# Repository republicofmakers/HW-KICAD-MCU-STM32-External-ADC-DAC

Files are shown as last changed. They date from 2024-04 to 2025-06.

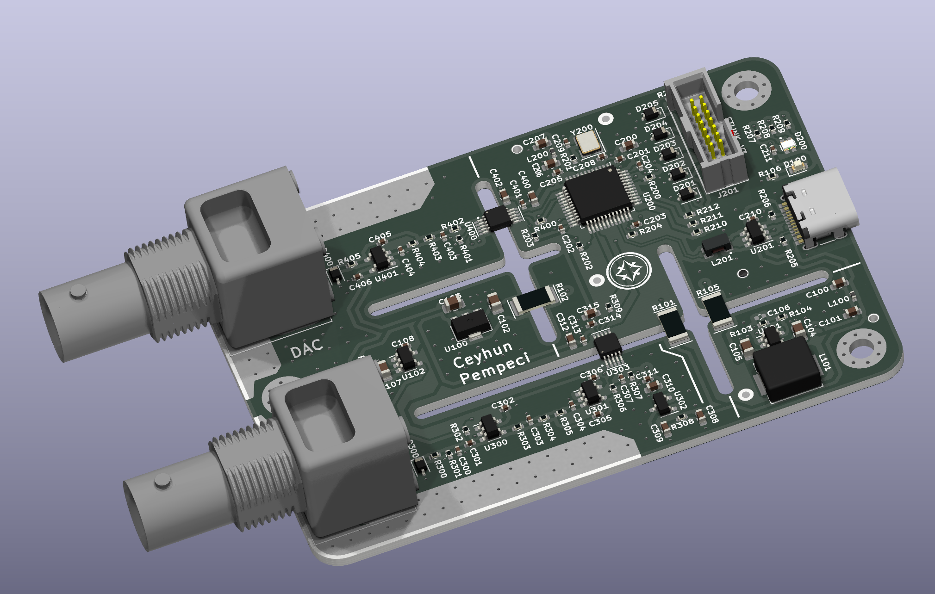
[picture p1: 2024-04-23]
Documents/Pictures/Picture-Front1.png

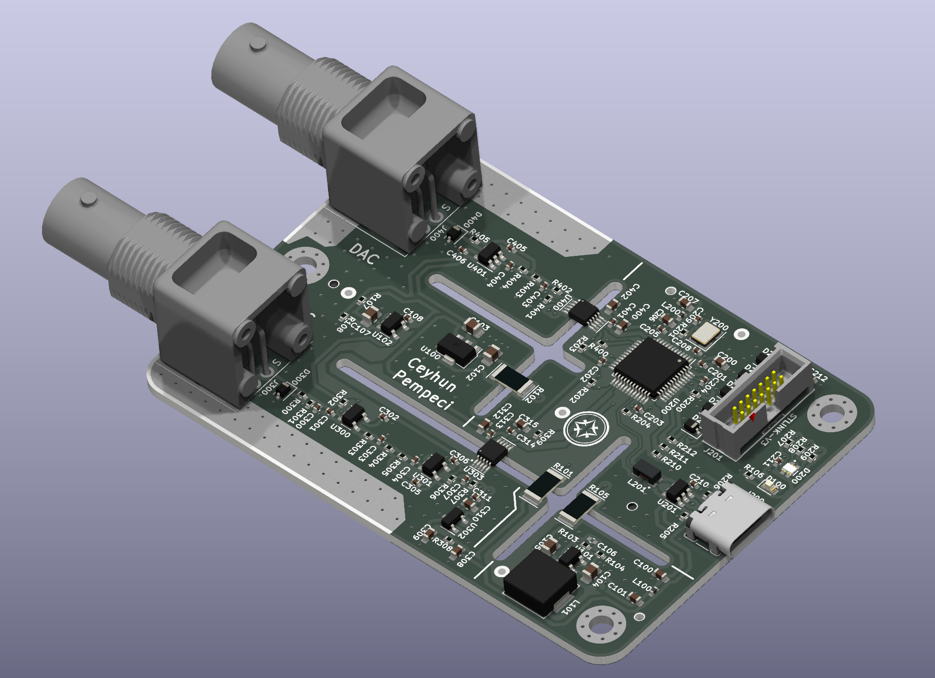
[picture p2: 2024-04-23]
Documents/Pictures/Picture-Front2.png

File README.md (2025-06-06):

# Mixed Signal Hardware Design

Picture-Front1
Image generated with Kicad 3D viewer.
  <br />
  
* You can download and check the project in Kicad.
* You can order this board (incl. SMT assembly) at https://www.jlcpcb.com. 
* Gerber and assembly files are in the relevant repo folders.

# With this project you can learn how to design:
* Switching voltage regulator and Low-dropout regulator
* STM32 MCU that using USB & SPI interface
* ADC / DAC integration
* Creating kalman filter for noise
* Also how to isolate the part with PCB cutouts for noise

NOTE:If you are an employer , you can check out my skills...

# Where can you use it?
* If you need many ADC or DAC readings, STM32 have limited number of ADC/DAC , such as if you design an SDD tester etc. 
* If you need more accurate readings, I used 14-Bit for ADC and 12-Bit for DAC but you can go 16-BIT or more...
* ADC => (ADC141S626 14-Bit, 50 kSPS to 250 kSPS)
* DAC => (DAC7563SDGSR 12-Bit, 0 to 3.3V)
* I used these parts because I had at my invertory, but I think you get the idea.
* If you need filtering for noise, kalman filters are so common in industry. Drones etc.<br />
Don't forget the test with LTSPICE.
<br />
<br />
* Take the project, adapt it , use it. I hope it helps you...

<br />
<br />

 **STM32F1 based ADC / DAC signal analyzer** 

 **Mixed Signal Hardware Design with Kicad** 

 **Created By Ceyhun Pempeci**

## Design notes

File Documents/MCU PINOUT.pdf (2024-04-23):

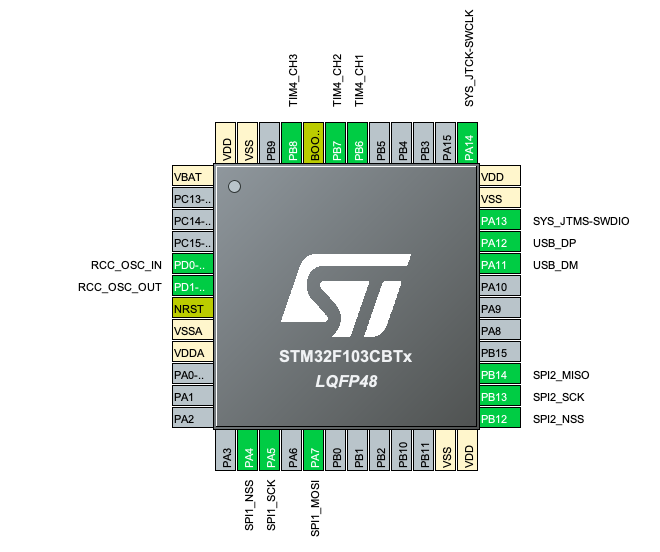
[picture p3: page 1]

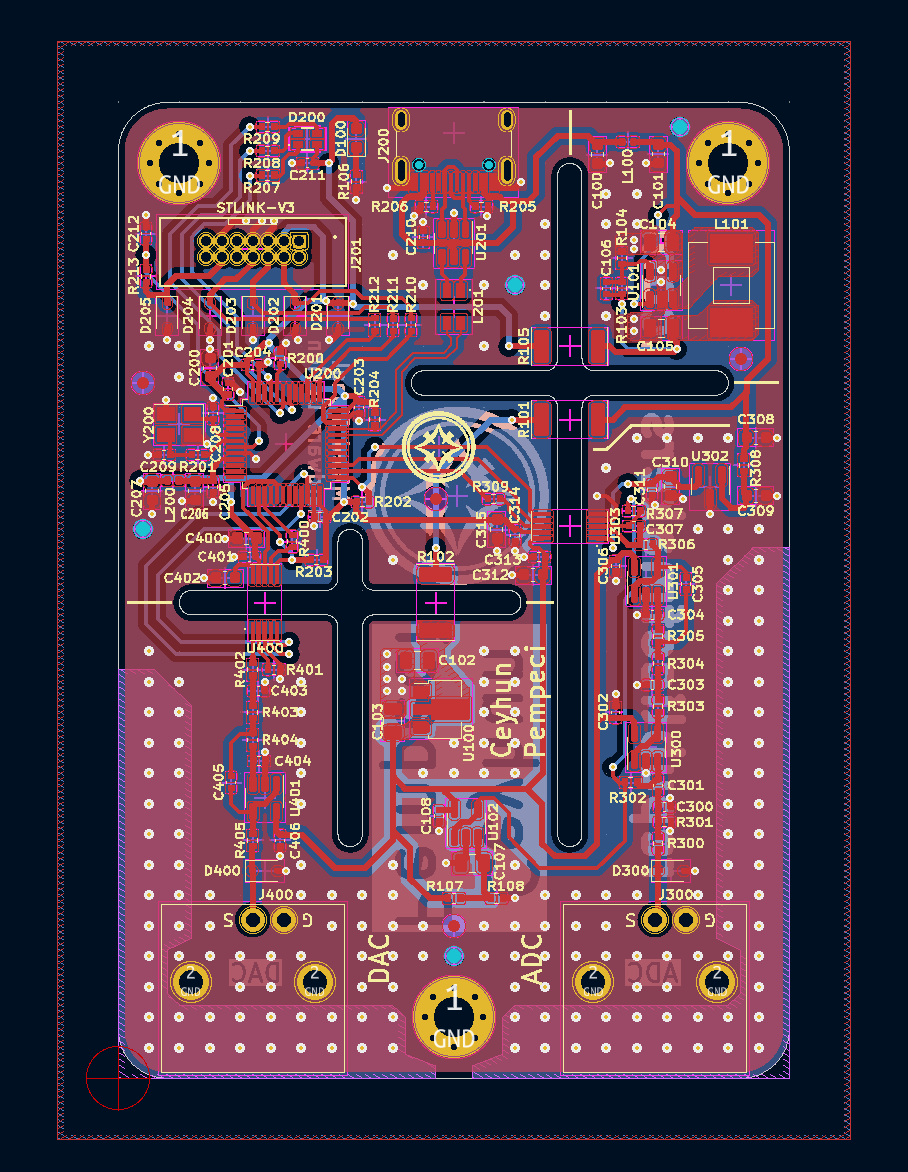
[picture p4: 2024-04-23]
Documents/Pictures/PCB-Final2.png

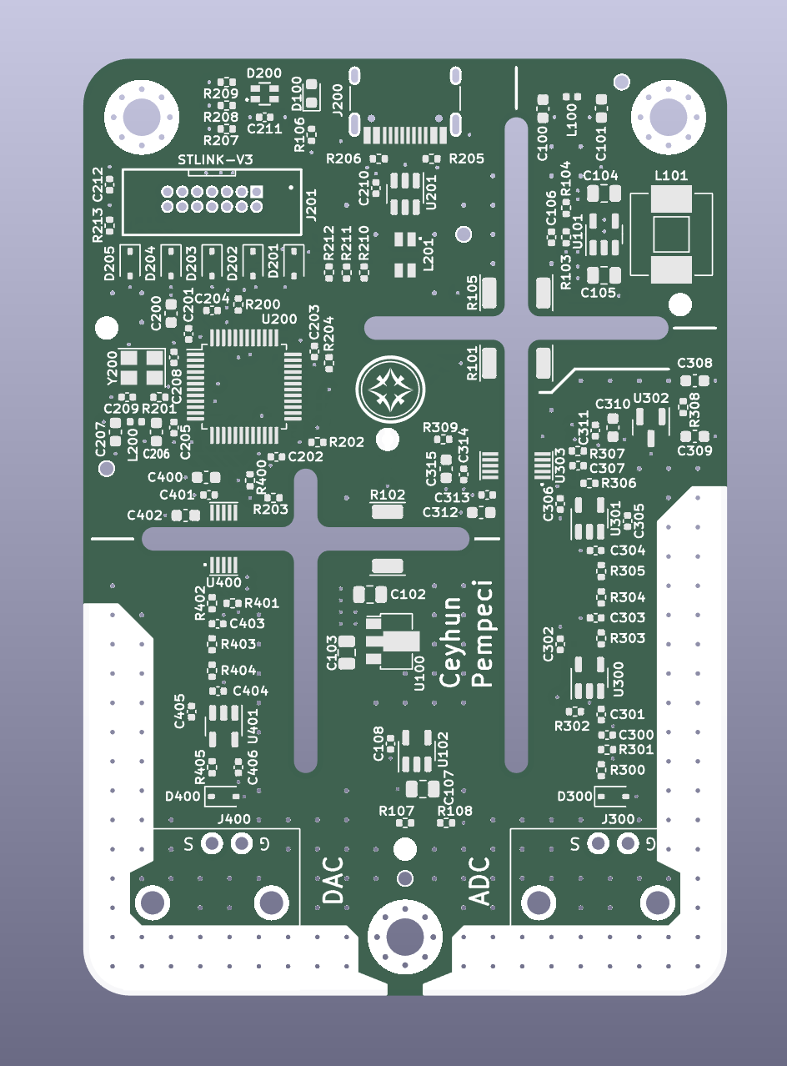
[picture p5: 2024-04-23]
Documents/Pictures/Picture-PCB-Raw.png

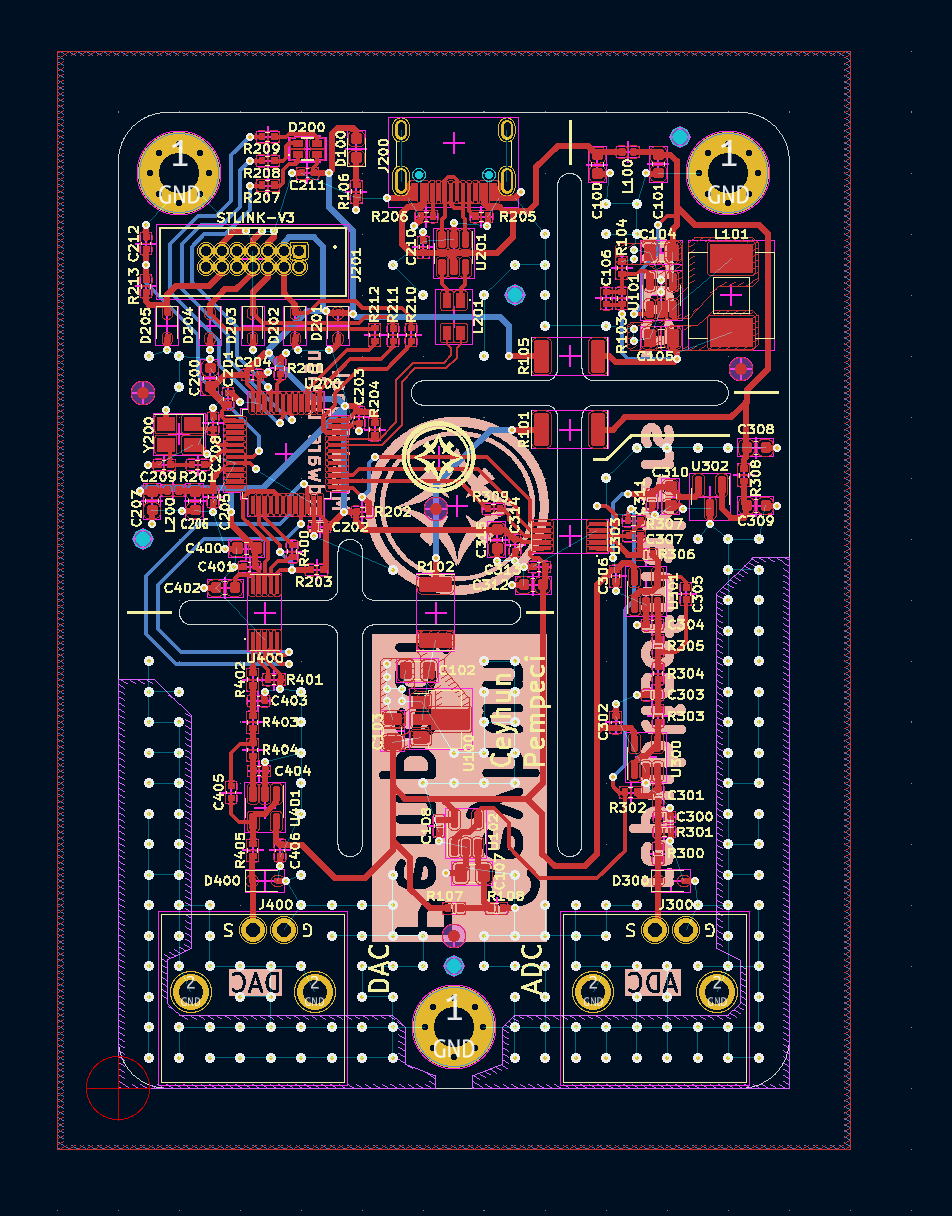
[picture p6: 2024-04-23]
Documents/Pictures/PCB-Final.png

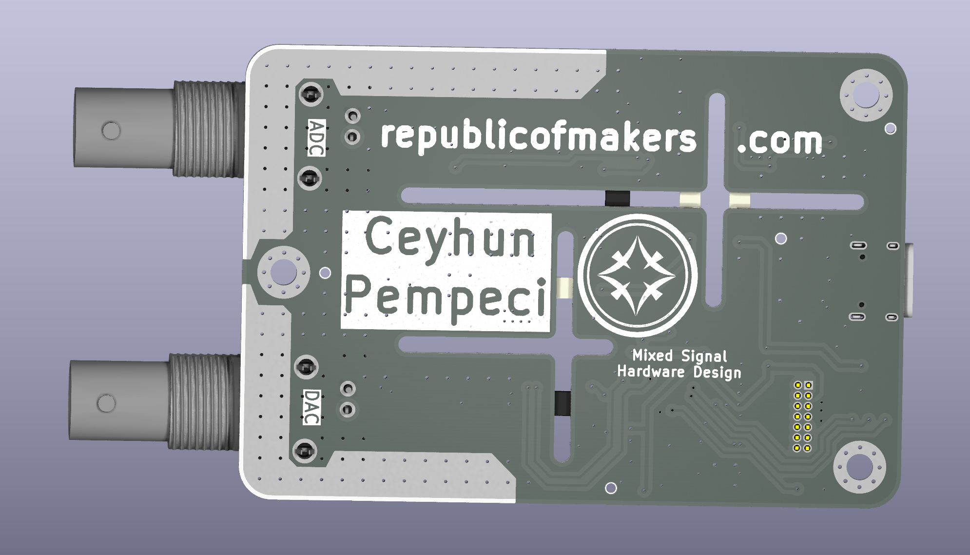
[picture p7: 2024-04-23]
Documents/Pictures/Picture_Back.png

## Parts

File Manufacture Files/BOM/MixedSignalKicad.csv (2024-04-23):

Comment | Designator | Footprint | LCSC
1u | C100,C101,C206,C207,C402 | Capacitor_SMD:C_0603_1608Metric | C15849
22u | C102,C103,C104,C105,C107 | Capacitor_SMD:C_0805_2012Metric | C377773
100n | C108,C201,C202,C203,C204,C210,C211,C212,C301,C302,C306,C311,C313,C314,C401,C406 | Capacitor_SMD:C_0402_1005Metric | C1525
10u | C200,C308,C309,C310,C312,C315,C400 | Capacitor_SMD:C_0603_1608Metric | C19702
10n | C205 | Capacitor_SMD:C_0402_1005Metric | C15195
10p | C208,C209 | Capacitor_SMD:C_0402_1005Metric | C32949
150p | C300,C304,C307,C404 | Capacitor_SMD:C_0402_1005Metric | C106998
1n | C303,C305,C403,C405 | Capacitor_SMD:C_0402_1005Metric | C1523
RED | D100 | LED_SMD:LED_0603_1608Metric | C2286
R6GHY5C-A01 | D200 | ceyhun:R6GHY5C-A01 | C2897364
PESD3V3L1BA,115 | D201,D202,D203,D204,D205,D300,D400 | Diode_SMD:D_SOD-323 | C51450
USB_C_Receptacle_USB2.0 | J200 | ceyhun:TYPE-C-31-M-12 | C165948
2x7 1.27mm | J201 | ceyhun:14 Pin IDC 1.27mm | C2935955
DOSIN-801-0031 | J300,J400 | ceyhun:AMPHENOL-BNC-031-5640-1010 | C521205
10n | L100,L200 | Inductor_SMD:L_0402_1005Metric | C27147
47u | L101 | ceyhun:MWSA0603S | C408455
CMF3216F-900-2P-T | L201 | ceyhun:CMC-1206 | C963740
0R | R101,R105 | Resistor_SMD:R_2010_5025Metric | C270958
10R | R102 | Resistor_SMD:R_2010_5025Metric | C324069
100k | R103 | Resistor_SMD:R_0402_1005Metric | C25741
22k | R104,R304,R403 | Resistor_SMD:R_0402_1005Metric | C25768
1k | R106,R107,R108,R207,R208,R209,R300,R306,R307 | Resistor_SMD:R_0402_1005Metric | C11702
10k | R200,R202,R203,R401 | Resistor_SMD:R_0402_1005Metric | C25744
0R | R201,R309,R400 | Resistor_SMD:R_0402_1005Metric | C17168
1k5 | R204 | Resistor_SMD:R_0402_1005Metric | C25867
5k1 | R205,R206 | Resistor_SMD:R_0402_1005Metric | C25905
49R9 | R210,R211,R212,R213,R308,R405 | Resistor_SMD:R_0402_1005Metric | C25120
2M2 | R301,R302 | Resistor_SMD:R_0402_1005Metric | C274901
6k8 | R303,R402 | Resistor_SMD:R_0402_1005Metric | C25917
12k | R305,R404 | Resistor_SMD:R_0402_1005Metric | C25752
HT7533-1 | U100 | Package_TO_SOT_SMD:SOT-89-3 | C14289
TLV62569DBV | U101 | Package_TO_SOT_SMD:SOT-23-5 | C141836
MCP6001T-E/OT | U102,U300,U301,U401 | Package_TO_SOT_SMD:SOT-23-5 | C29429
STM32F103CBT6 | U200 | Package_QFP:LQFP-48_7x7mm_P0.5mm | C8304
USBLC6-2SC6 | U201 | Package_TO_SOT_SMD:SOT-23-6 | C7519
REF3033AIDBZT | U302 | Package_TO_SOT_SMD:SOT-23 | C2872391
ADC141S626CIMM_NOPB | U303 | ceyhun:VSSOP-10 | C206494
DAC7563SDGSR | U400 | ceyhun:VSSOP-10 | C601656
16MHz | Y200 | Crystal:Crystal_SMD_3225-4Pin_3.2x2.5mm | C13738

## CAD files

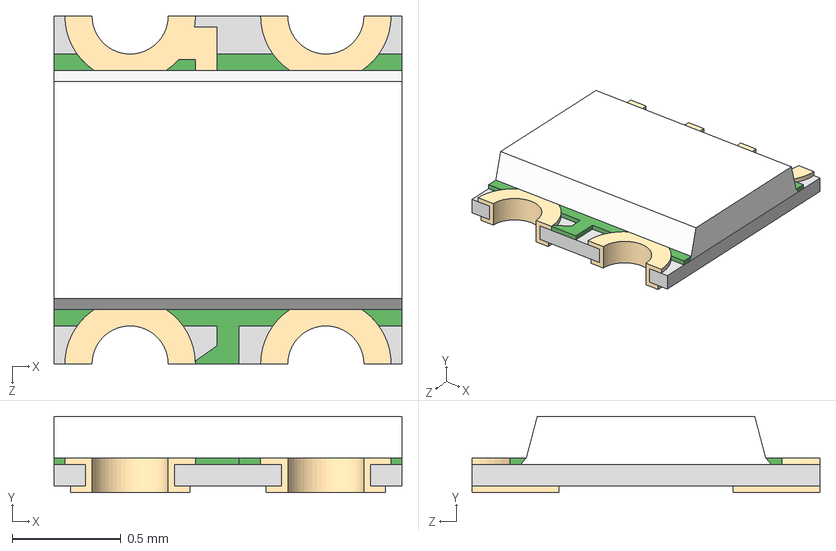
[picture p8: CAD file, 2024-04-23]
MixedSignalKicad/3D Models/19-237:R6GHY5C-A01:2T/19-237:R6GHY5C-A01:2T.STEP
1.60 x 0.35 x 1.60 mm

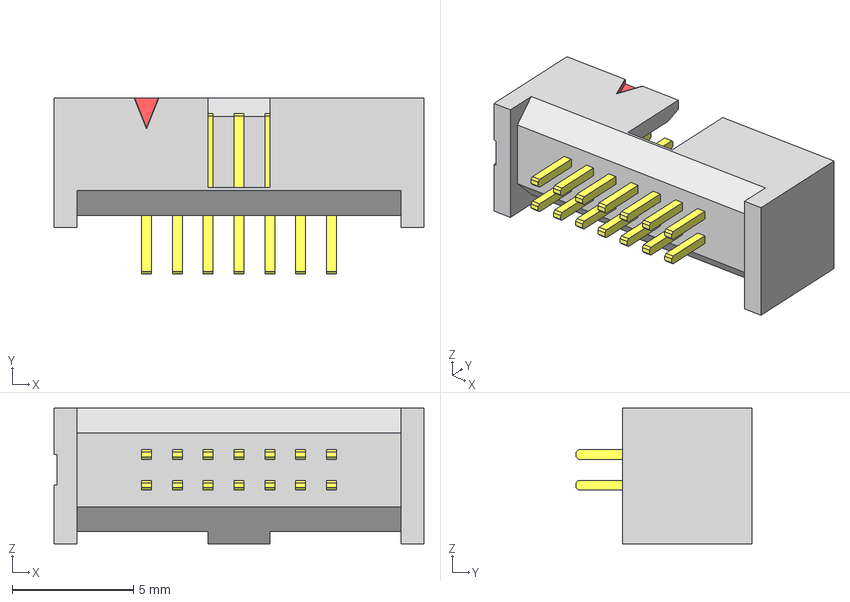
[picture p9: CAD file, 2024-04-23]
MixedSignalKicad/3D Models/IDC 14 pin 1.27mm/SHF-107-01-L-D-TH-TR.stp
15.2 x 7.24 x 5.59 mm
SHF-107-01-D_header
SHF-First_Position_Indicator
T-1S71-02-07-D-TH

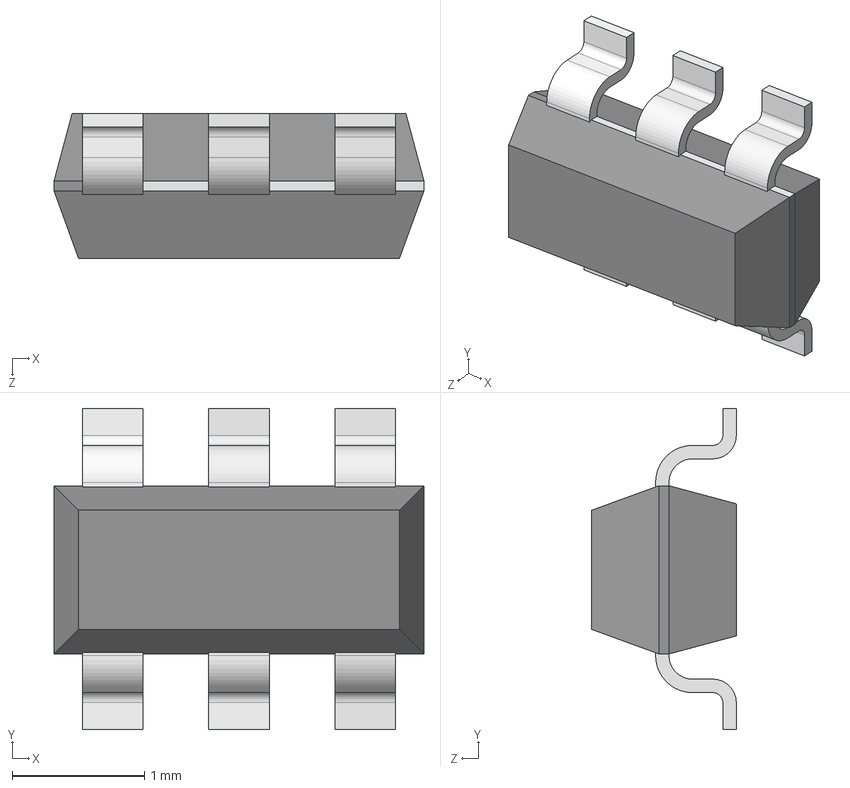
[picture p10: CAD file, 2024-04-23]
MixedSignalKicad/3D Models/SOT-23-6.step
2.79 x 2.43 x 1.09 mm

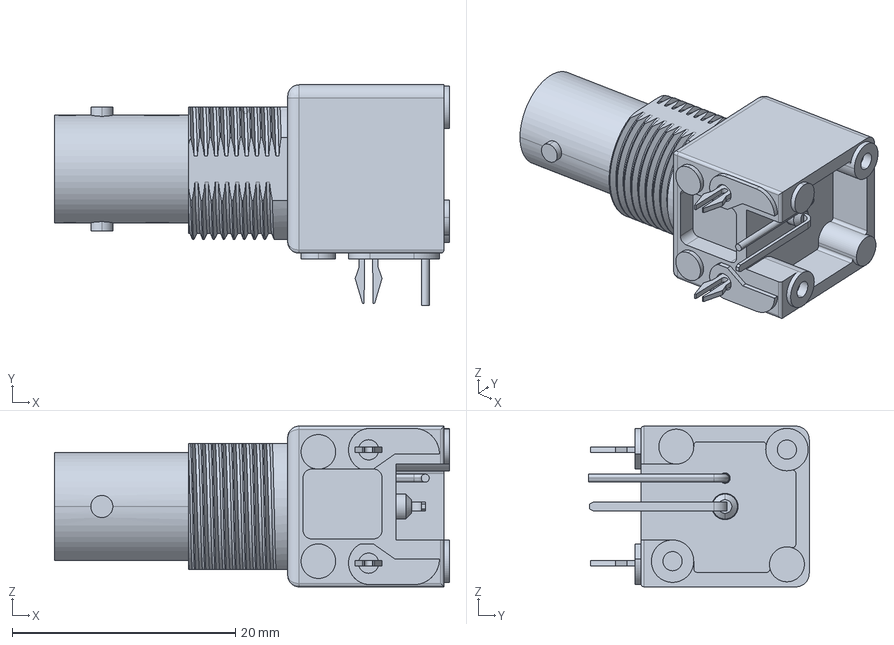
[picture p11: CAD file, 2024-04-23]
MixedSignalKicad/3D Models/31-5640-1010.stp
35.4 x 19.8 x 14.4 mm

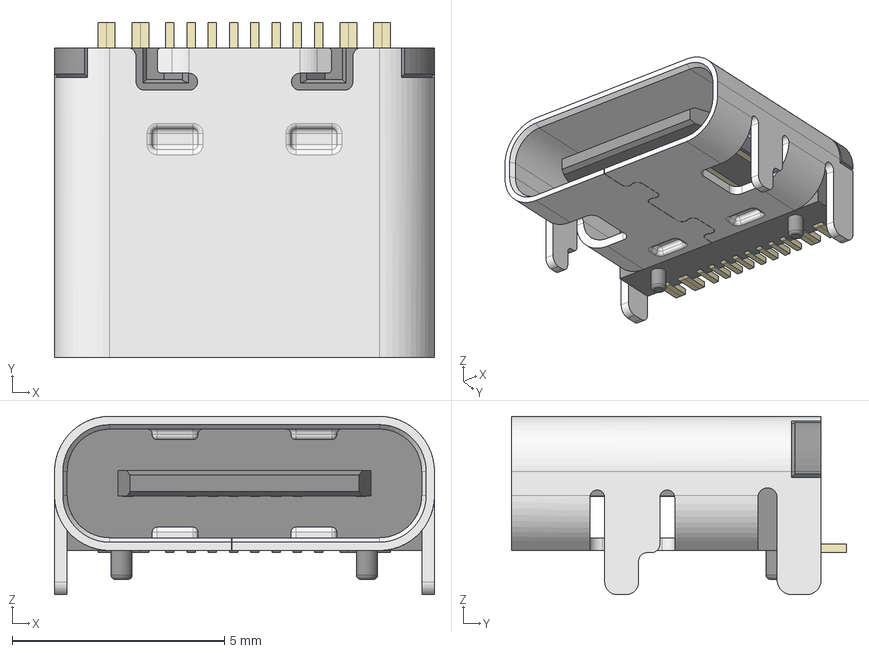
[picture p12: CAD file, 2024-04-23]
MixedSignalKicad/3D Models/HRO_TYPE-C-31-M-12.step
8.95 x 7.90 x 4.20 mm

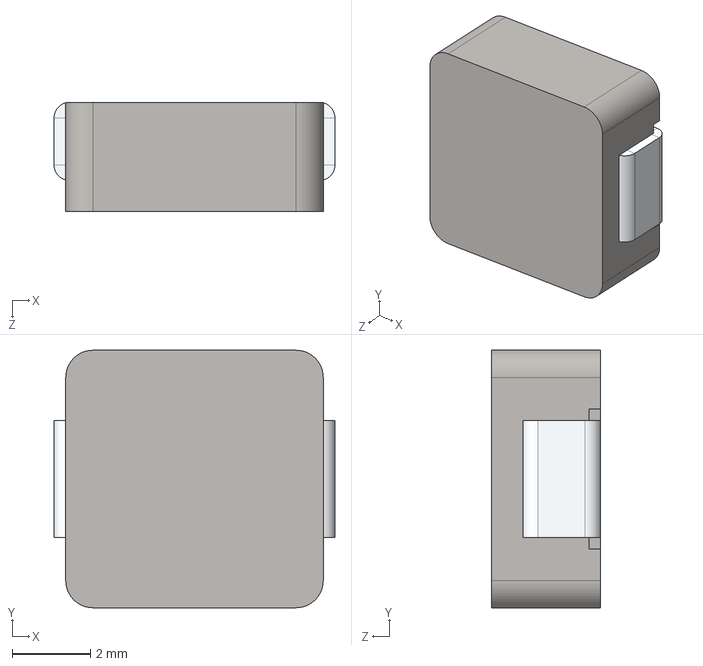
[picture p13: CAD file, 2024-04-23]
MixedSignalKicad/3D Models/User Library-MWSA0603S.STEP
7.20 x 6.60 x 2.80 mm
MWSA0603S-HOUSE.STP
MWSA0603S-PIN.STP

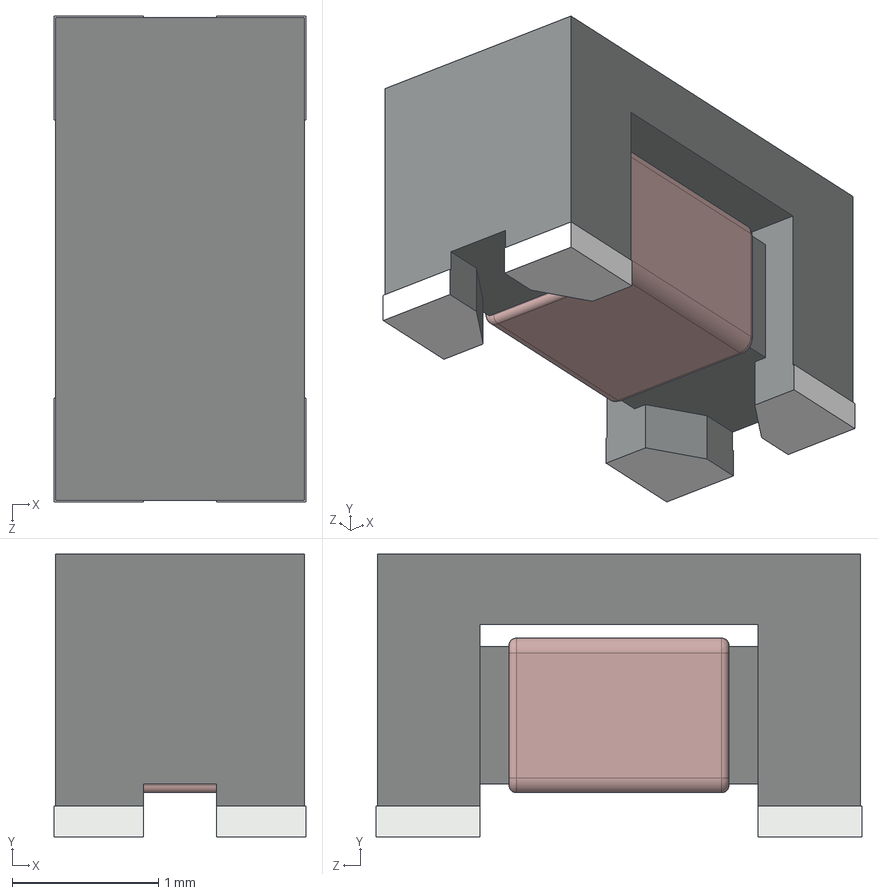
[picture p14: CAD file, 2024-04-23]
MixedSignalKicad/3D Models/Coilcraft-1206USB.STEP
1.72 x 1.93 x 3.32 mm

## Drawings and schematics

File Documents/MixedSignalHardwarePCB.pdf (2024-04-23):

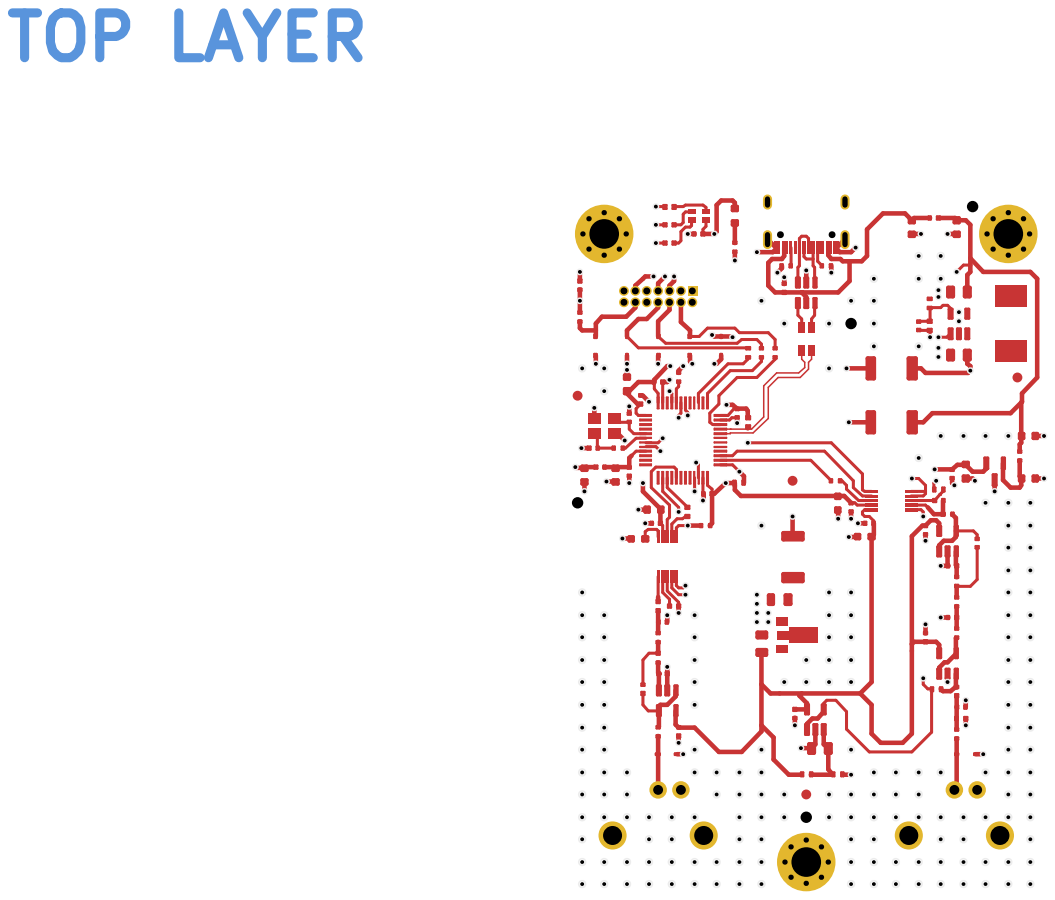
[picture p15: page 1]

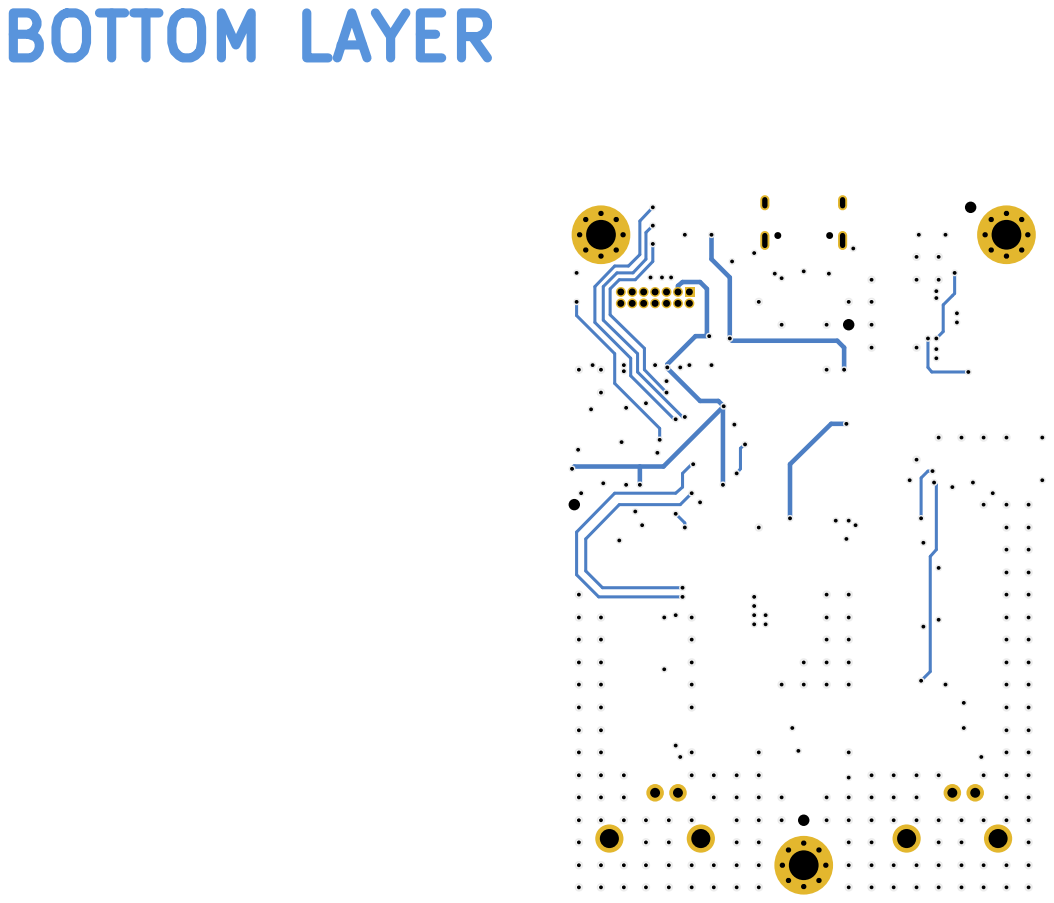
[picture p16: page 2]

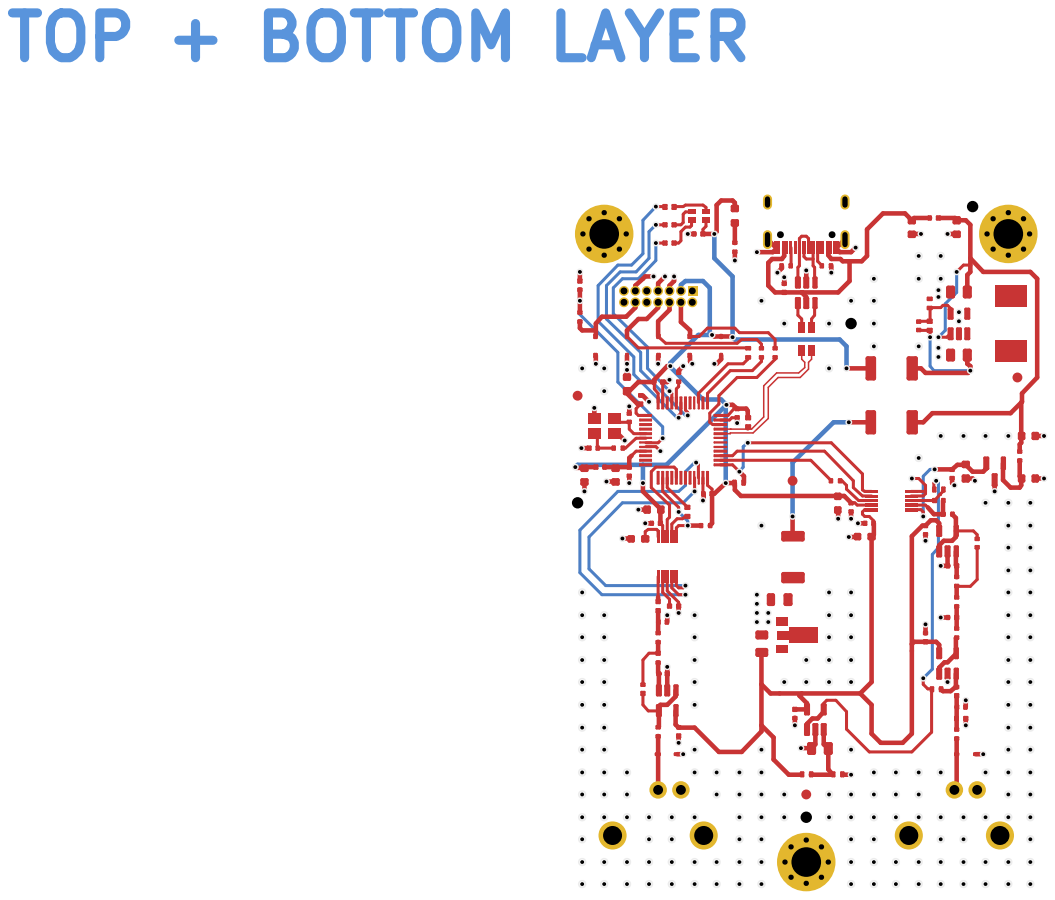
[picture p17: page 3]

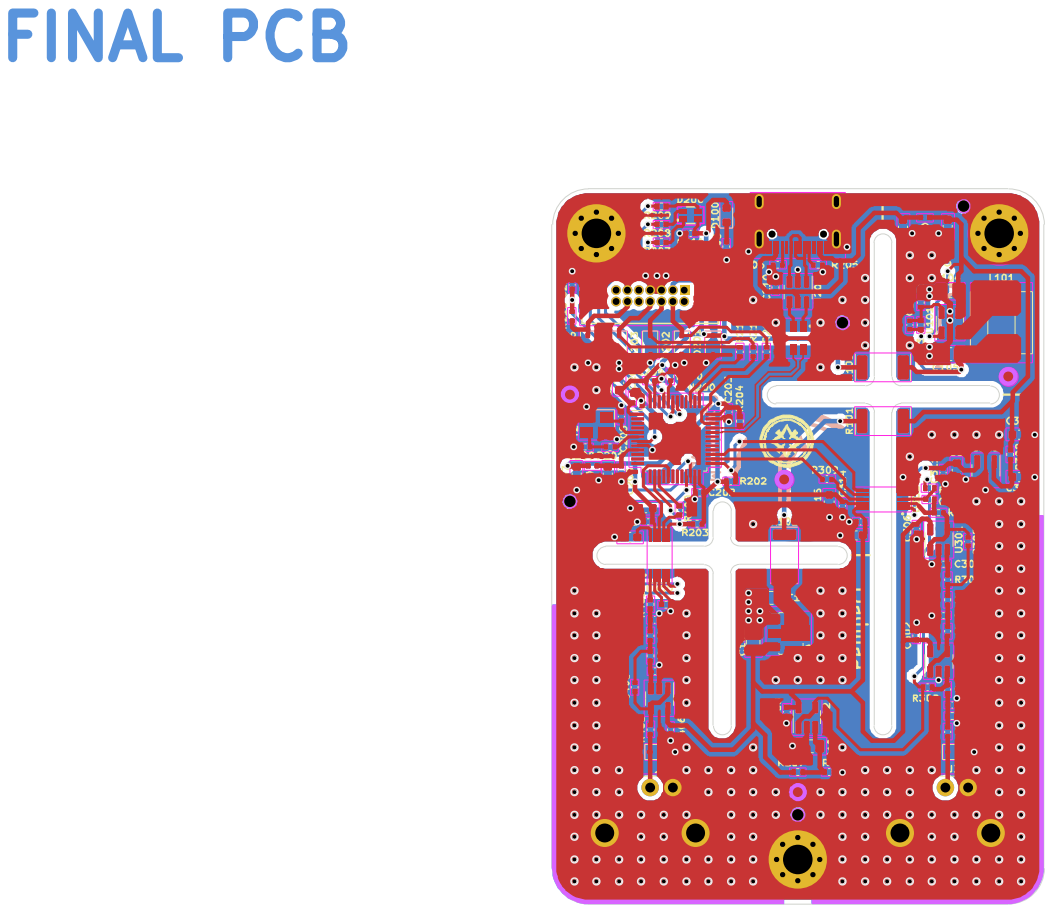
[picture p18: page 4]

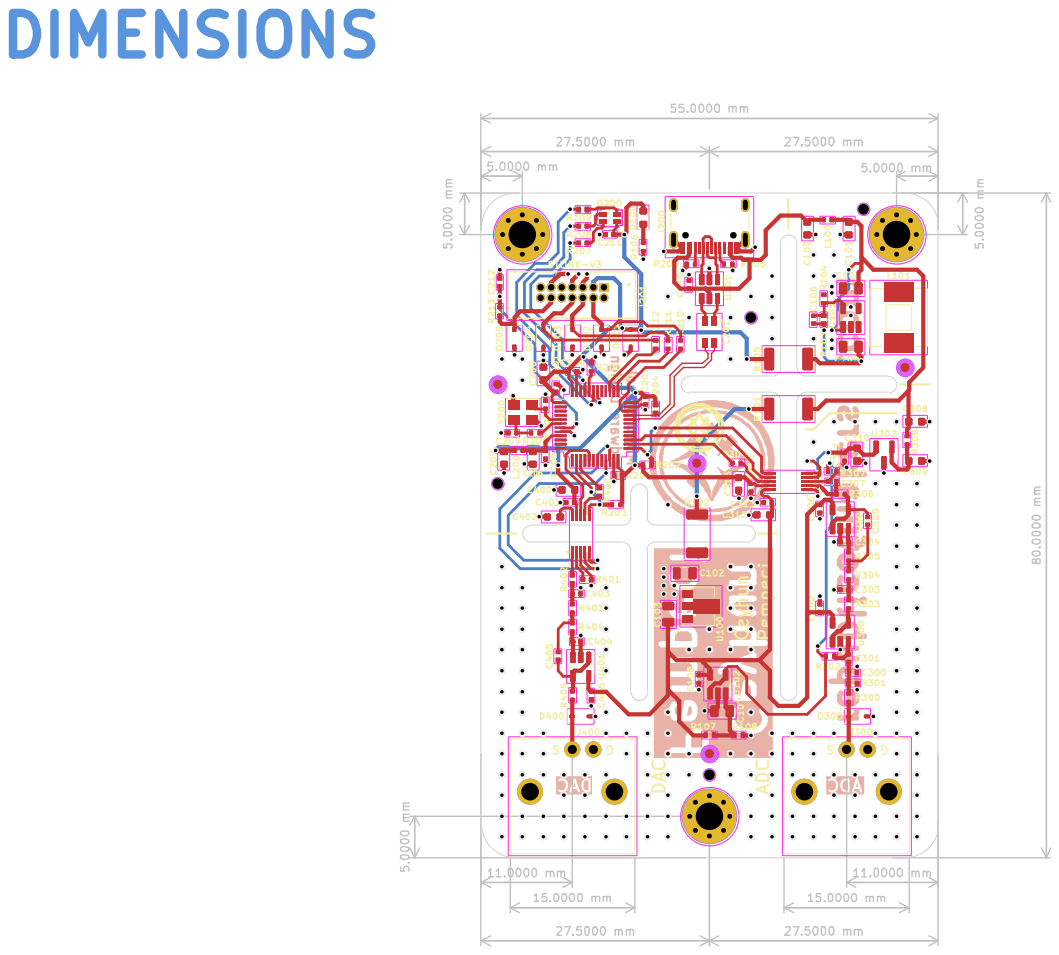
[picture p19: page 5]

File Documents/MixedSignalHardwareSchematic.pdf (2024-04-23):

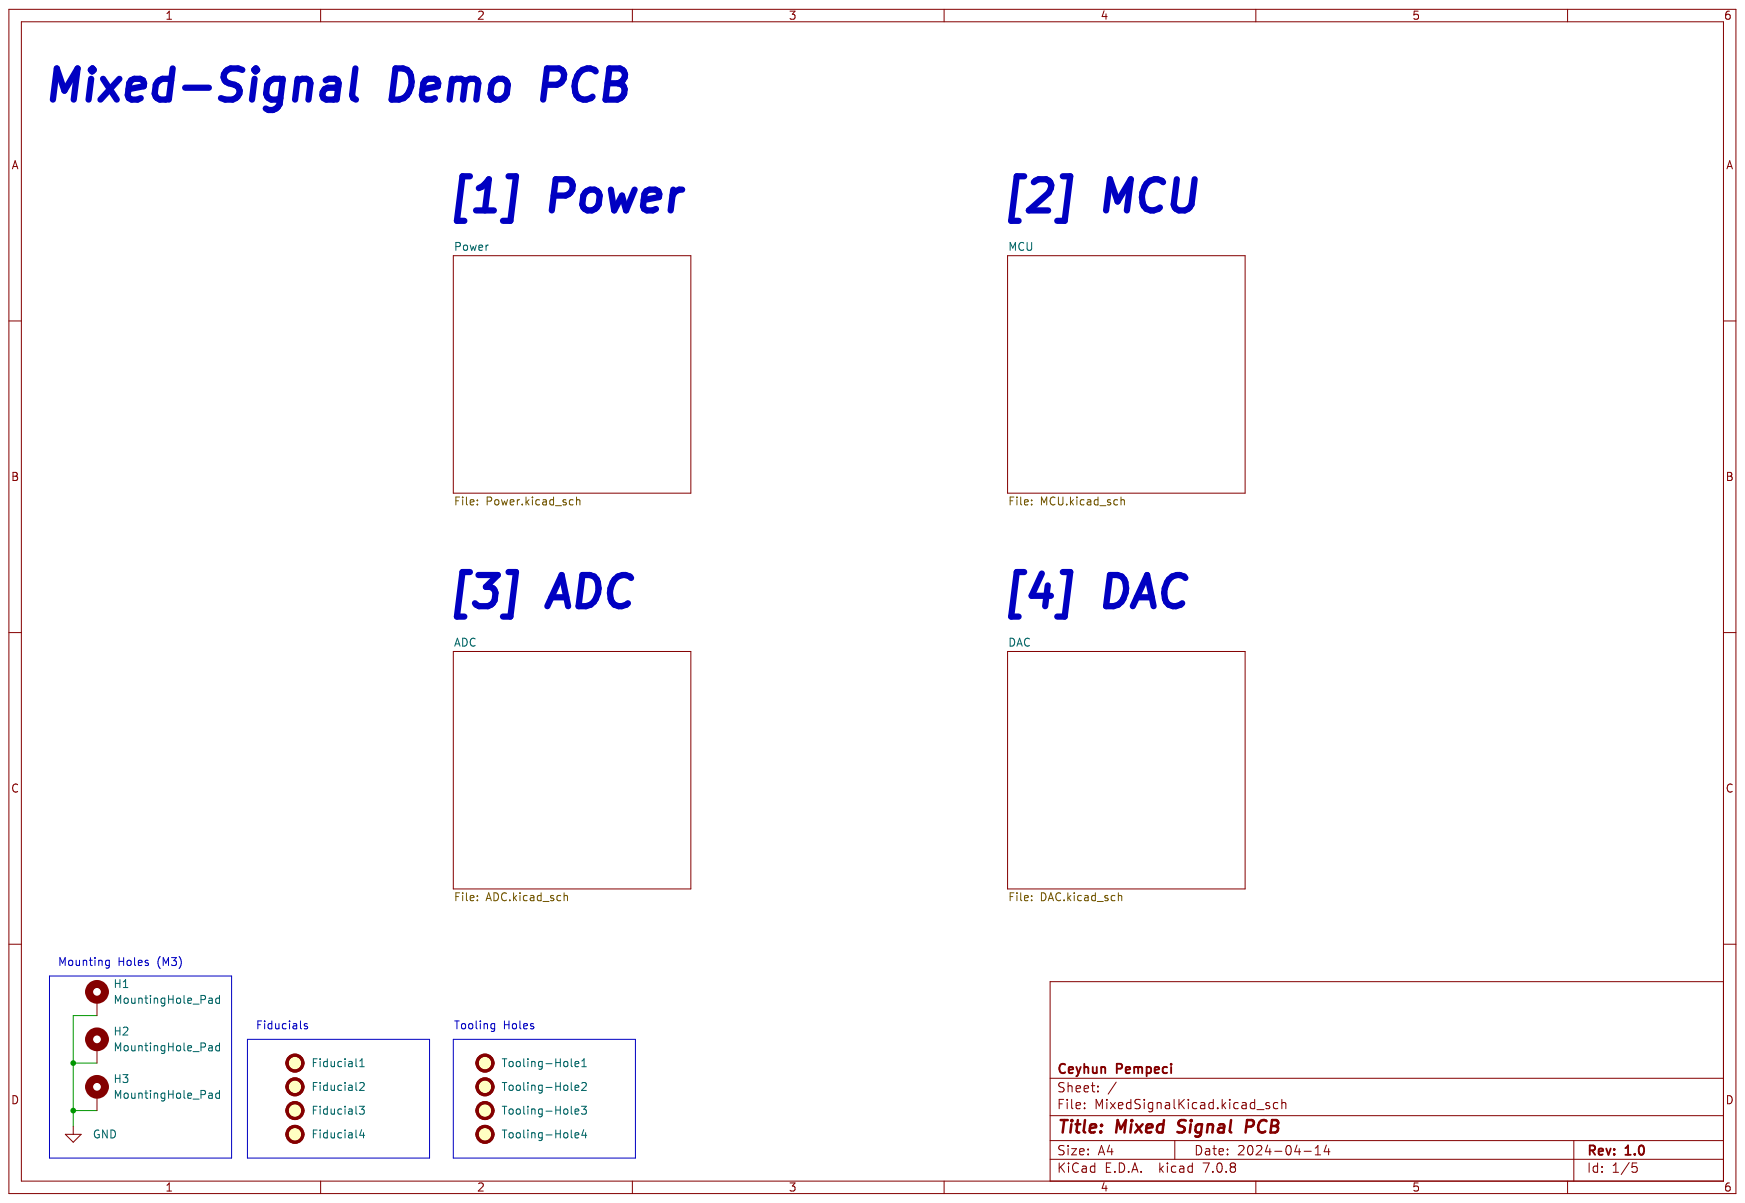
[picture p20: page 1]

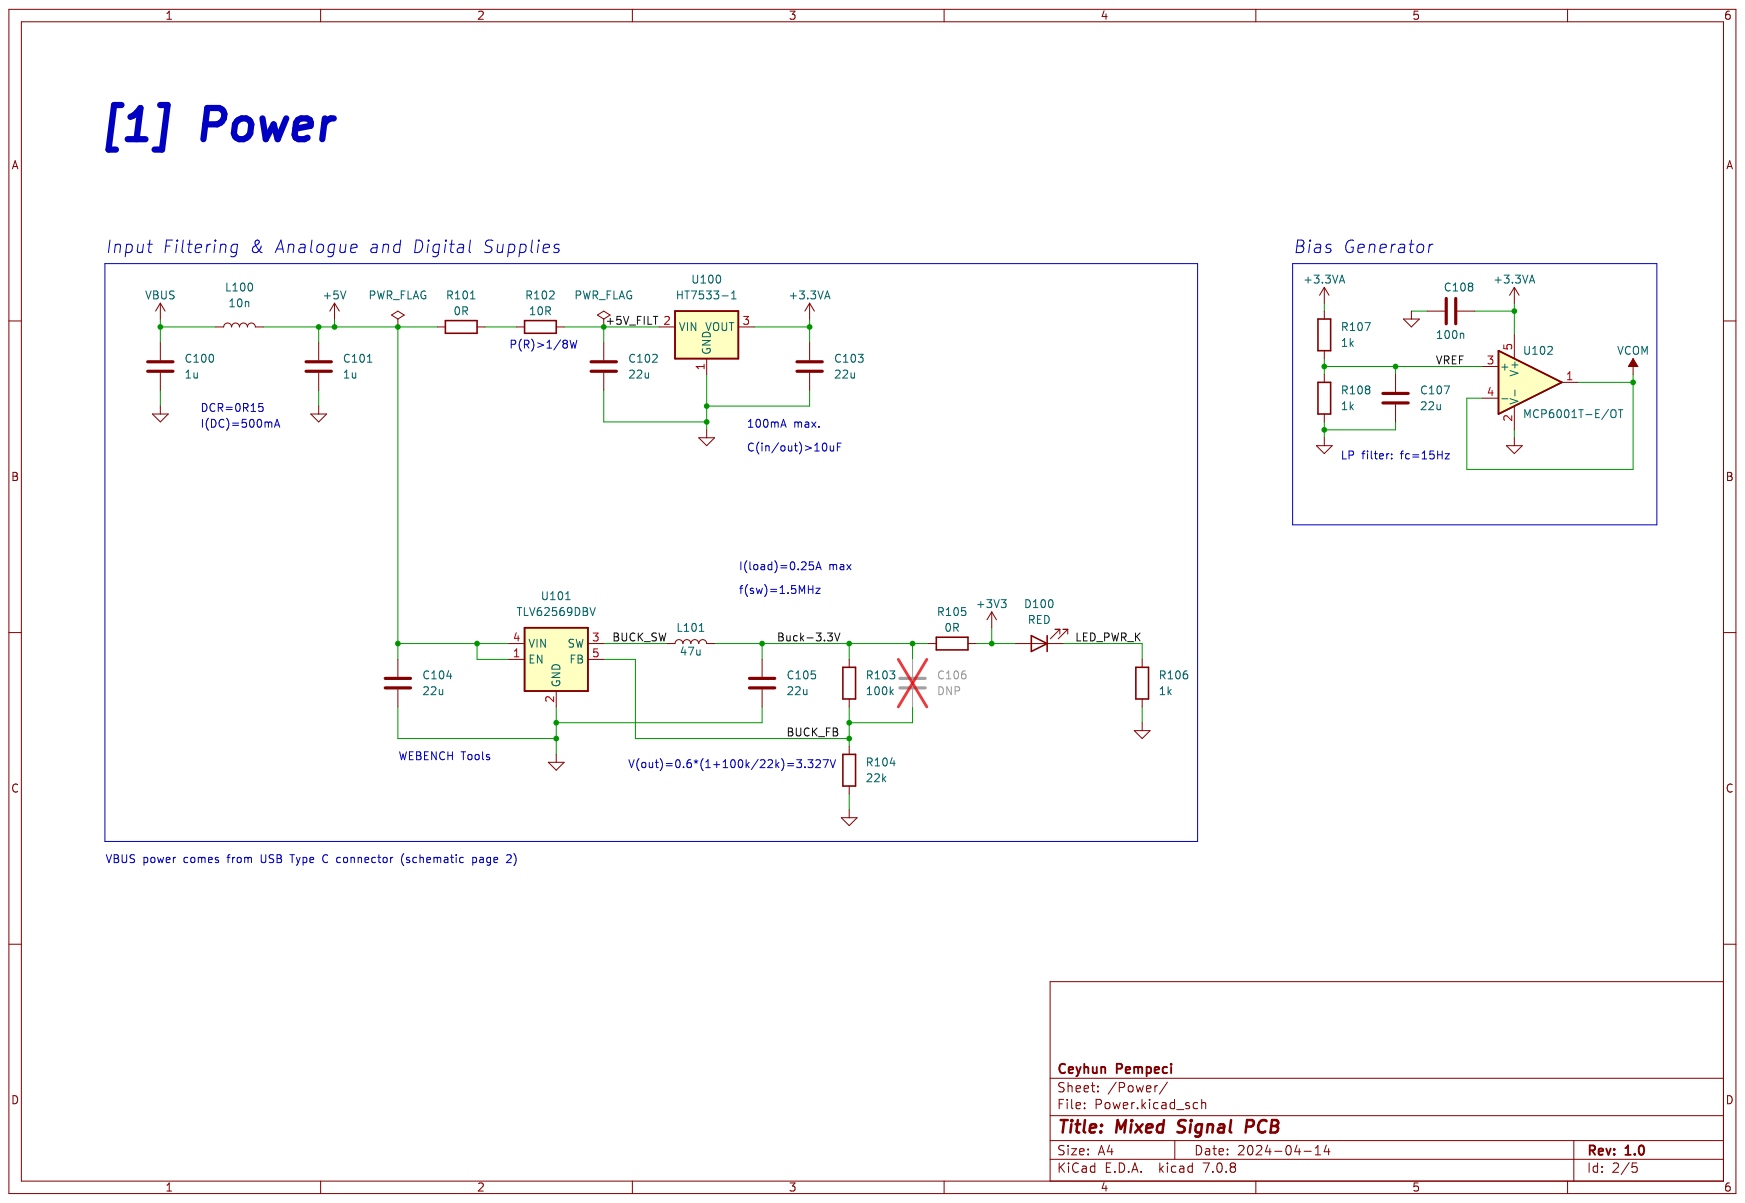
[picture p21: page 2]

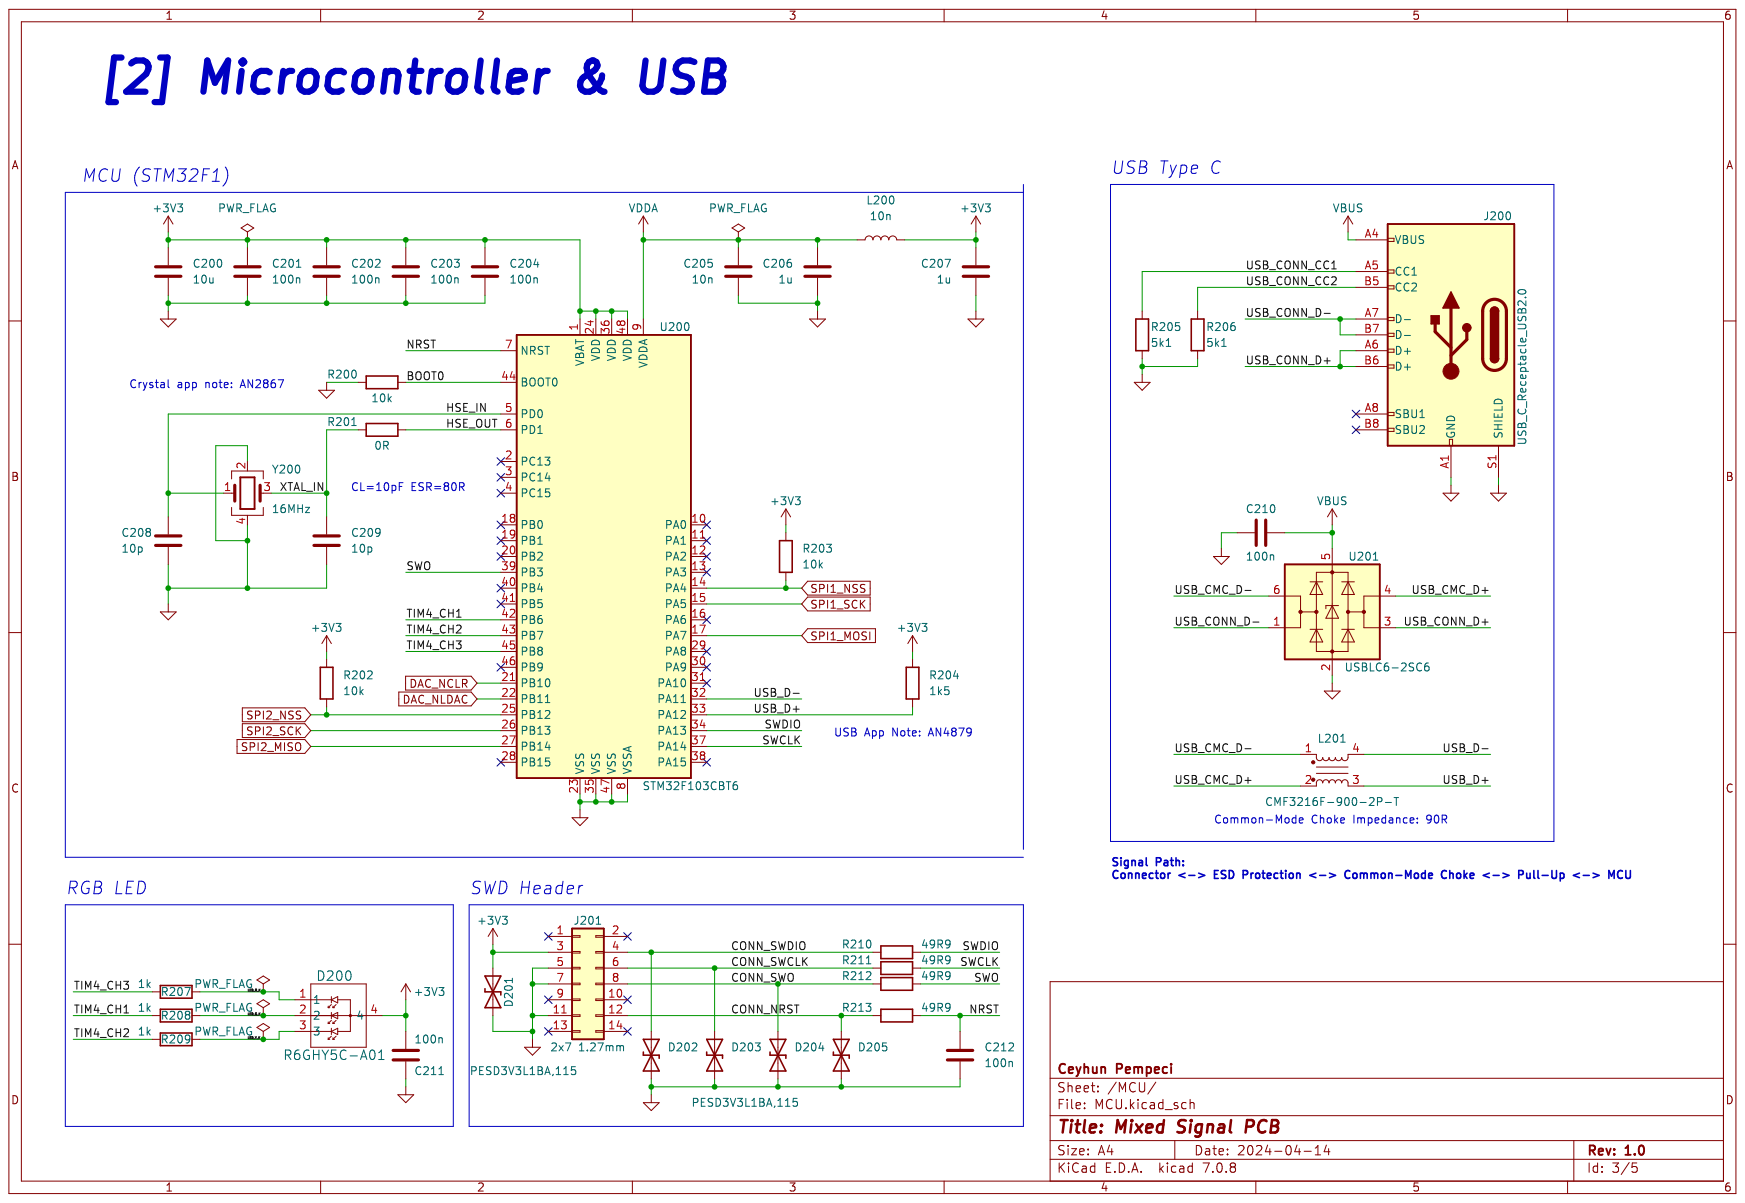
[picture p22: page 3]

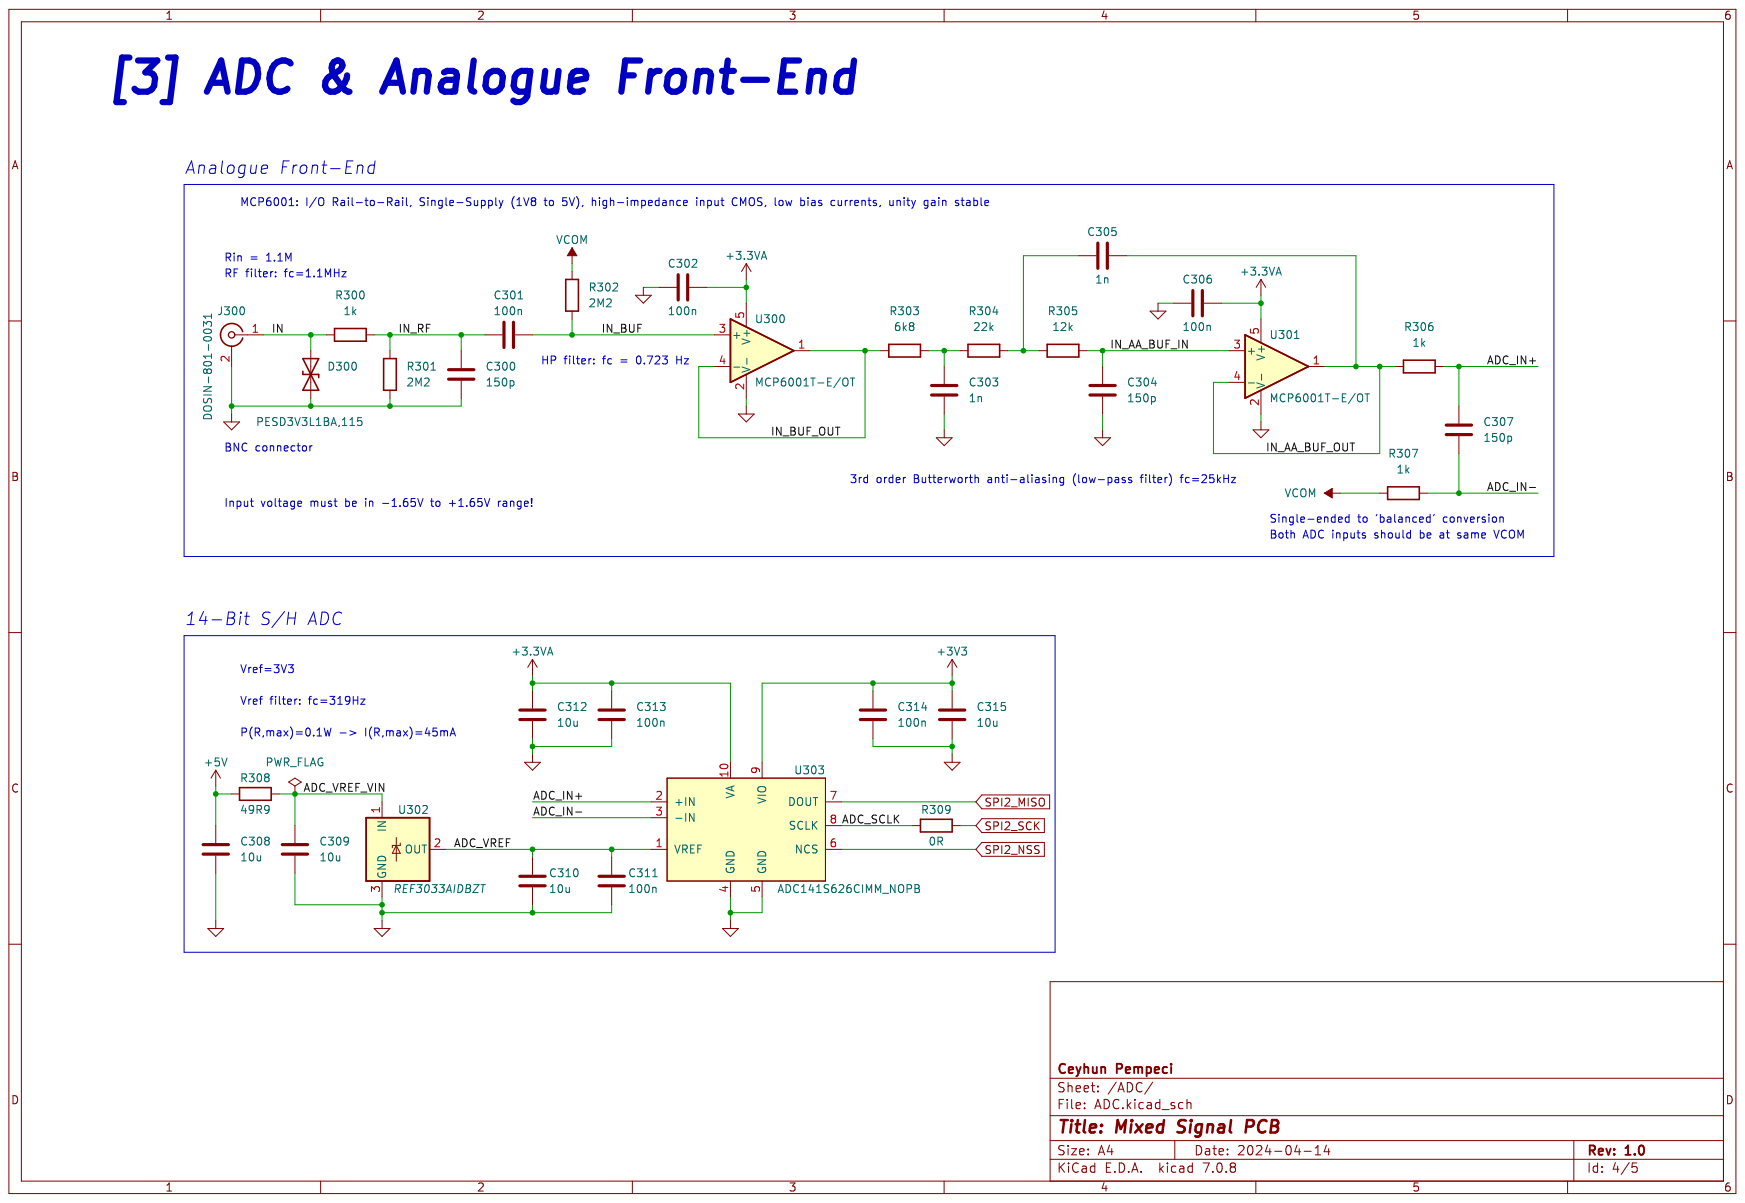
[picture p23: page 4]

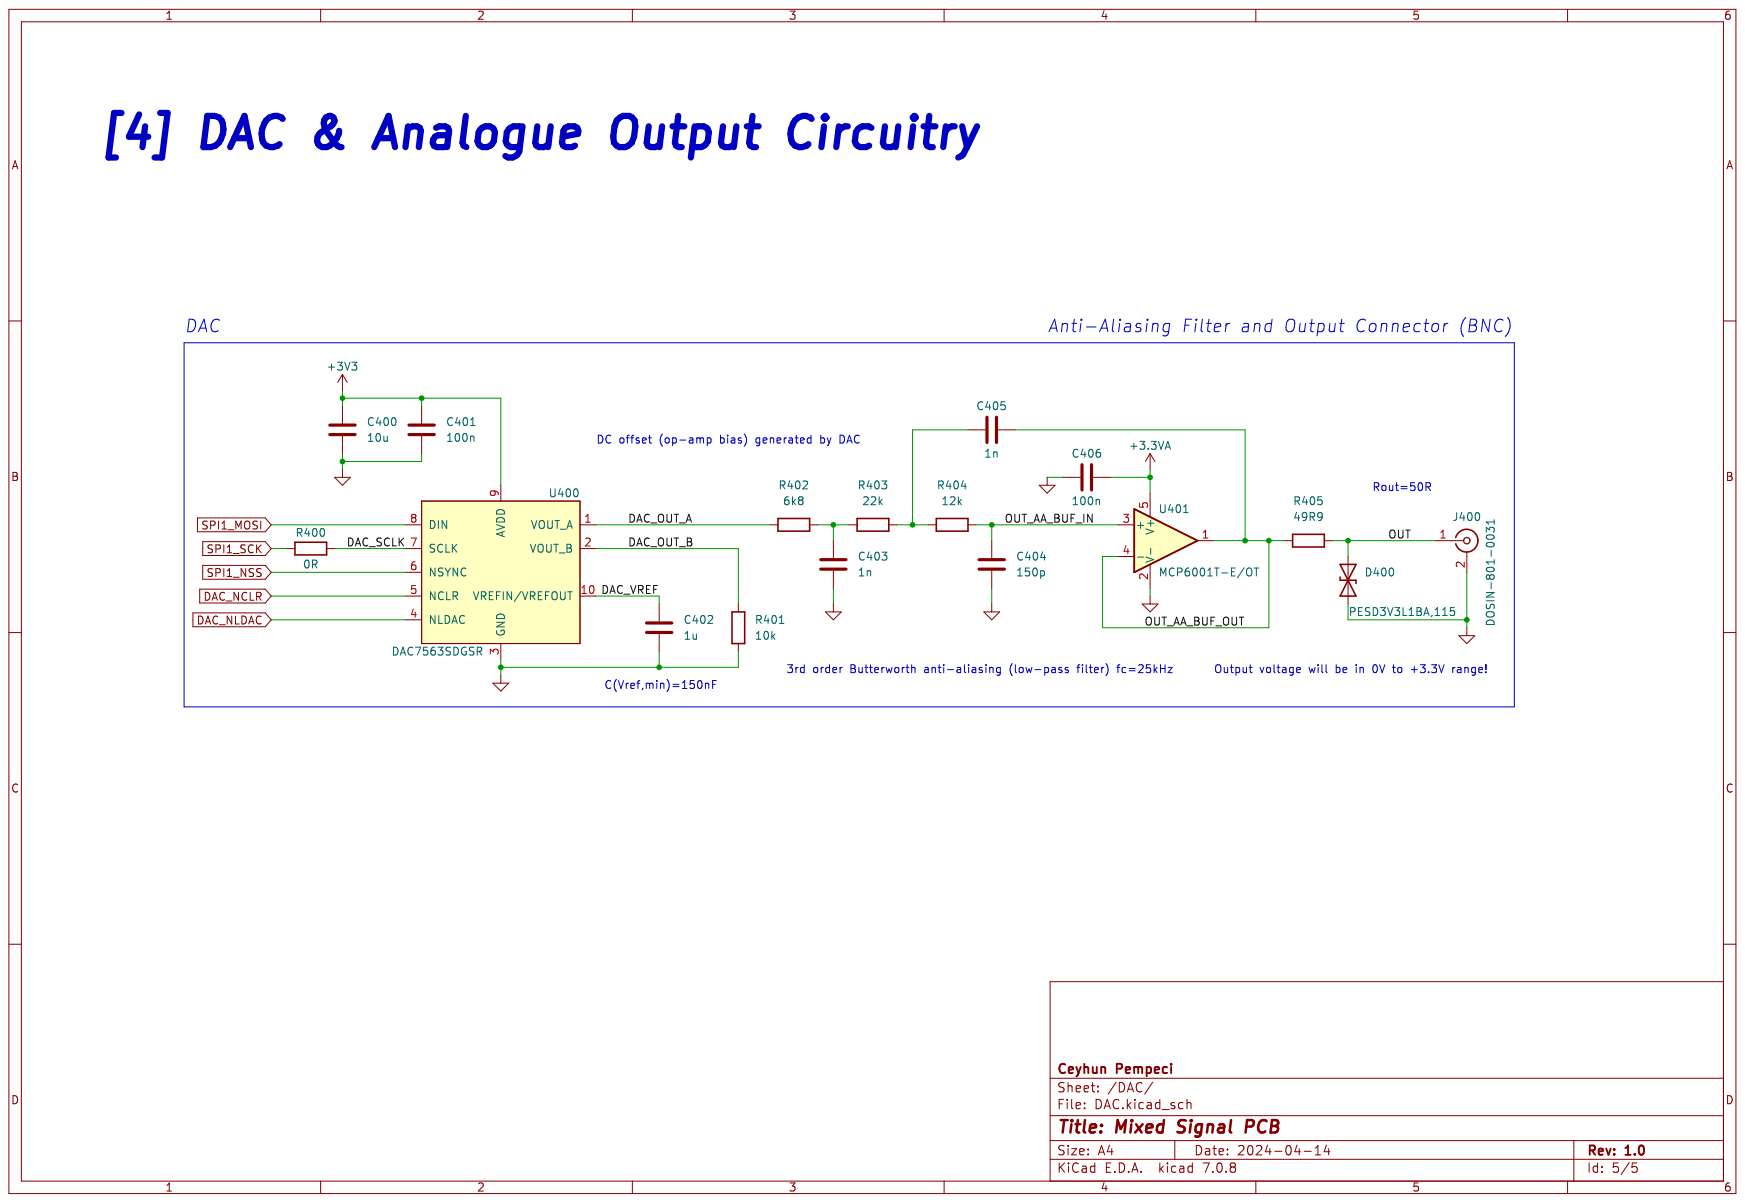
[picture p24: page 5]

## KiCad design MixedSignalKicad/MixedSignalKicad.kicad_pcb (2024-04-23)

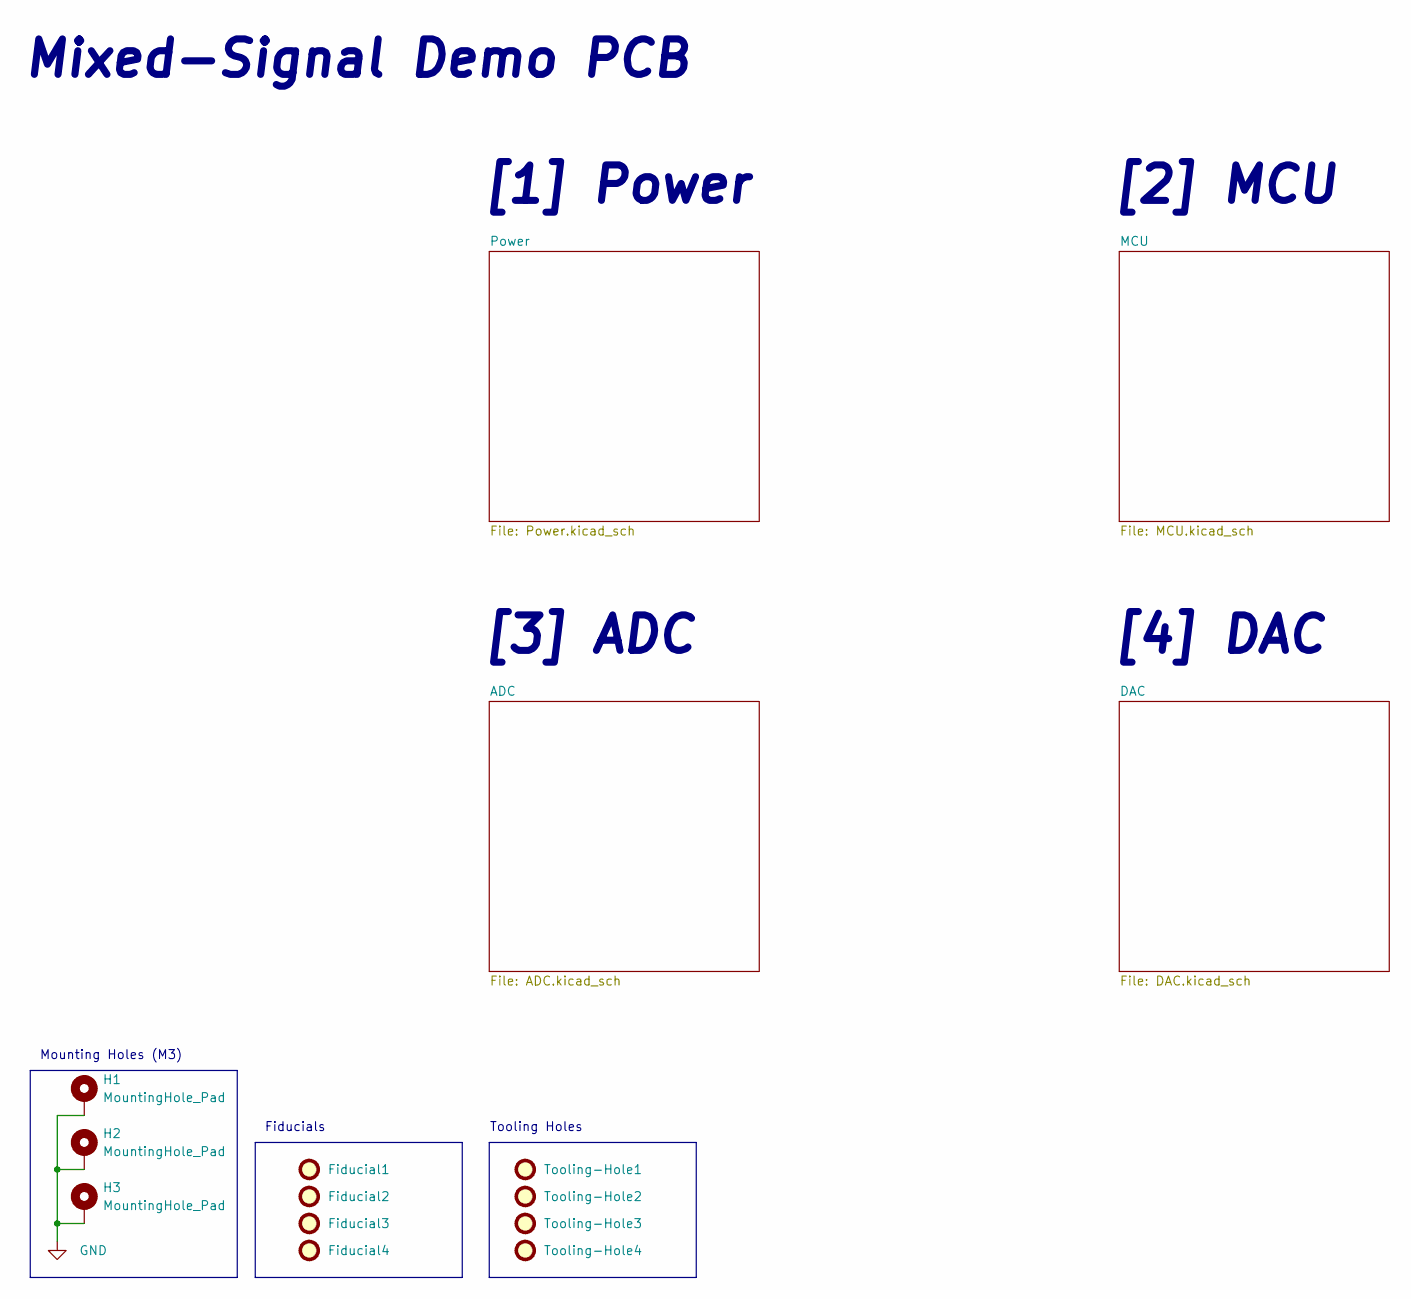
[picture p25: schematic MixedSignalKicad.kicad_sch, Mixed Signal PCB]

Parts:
Fiducial1, Fiducial2, Fiducial3, Fiducial4: Fiducial_1mm_Mask2mm
H1, H2, H3: MountingHole_Pad; MountingHole_3.2mm_M3_Pad_Via
Tooling-Hole1, Tooling-Hole2, Tooling-Hole3, Tooling-Hole4: ToolingHole

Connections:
GND: H1.1, H2.1, H3.1; also elsewhere on the board

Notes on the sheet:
[4] DAC
Mixed-Signal Demo PCB
Fiducials
[3] ADC
Mounting Holes (M3)
[2] MCU
Tooling Holes
[1] Power

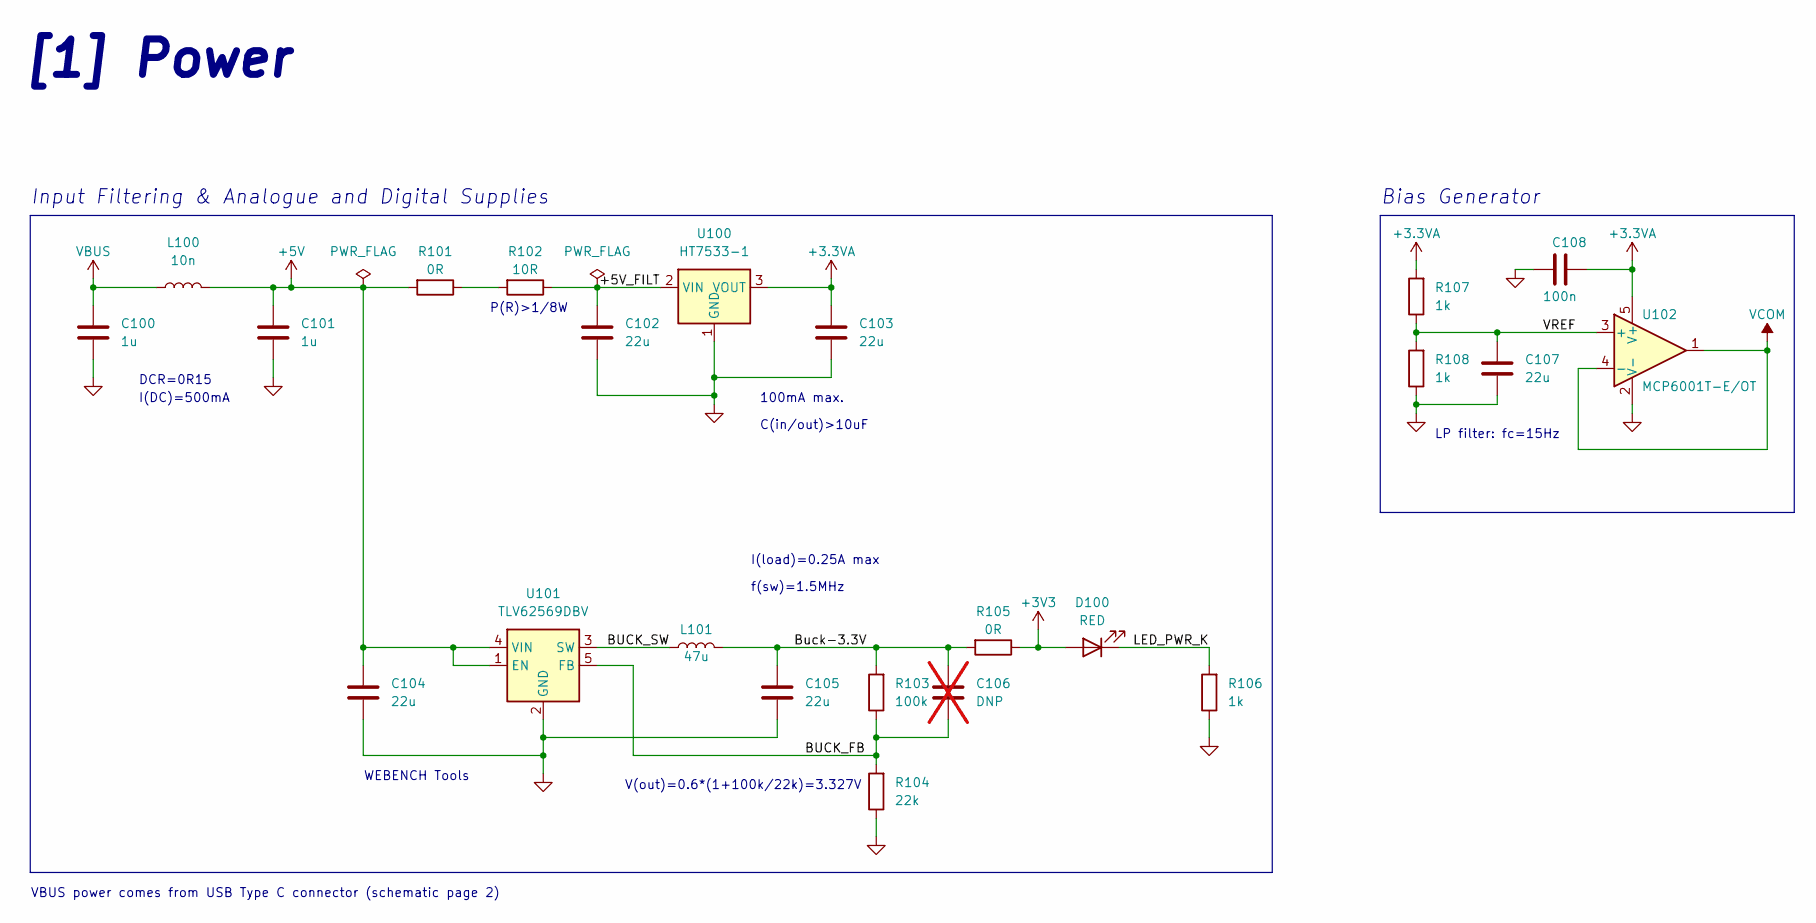
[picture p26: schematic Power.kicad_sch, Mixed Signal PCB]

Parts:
C100, C101: 1u; C_0603_1608Metric; LCSC C15849
C102, C103, C104, C105, C107: 22u; C_0805_2012Metric; LCSC C377773
C106: DNP; C_0402_1005Metric; not fitted
C108: 100n; C_0402_1005Metric; LCSC C1525
D100: RED; LED_0603_1608Metric; LCSC C2286
L100: 10n; L_0402_1005Metric; LCSC C27147
L101: 47u; MWSA0603S; LCSC C408455
R101, R105: 0R; R_2010_5025Metric; LCSC C270958
R102: 10R; R_2010_5025Metric; LCSC C324069
R103: 100k; R_0402_1005Metric; LCSC C25741
R104: 22k; R_0402_1005Metric; LCSC C25768
R106, R107, R108: 1k; R_0402_1005Metric; LCSC C11702
U100: HT7533-1; SOT-89-3; LCSC C14289
U101: TLV62569DBV; SOT-23-5; LCSC C141836
U102: MCP6001T-E/OT; SOT-23-5; LCSC C29429

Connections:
+3.3VA: C103.1, C108.1, R107.2, U100.3 (VOUT), U102.5 (V+); also elsewhere on the board
+3V3: D100.2 (A), R105.1; also elsewhere on the board
+5V: C101.1, C104.1, L100.2, R101.2, U101.1 (EN), U101.4 (VIN); also elsewhere on the board
/Power/+5V_FILT: C102.1, R102.1, U100.2 (VIN)
/Power/BUCK_FB: C106.2, R103.1, R104.2, U101.5 (FB)
/Power/BUCK_SW: L101.1, U101.3 (SW)
/Power/Buck-3.3V: C105.1, C106.1, L101.2, R103.2, R105.2
/Power/LED_PWR_K: D100.1 (K), R106.2
/Power/VREF: C107.1, R107.1, R108.2, U102.3 (+)
GND: C100.2, C101.2, C102.2, C103.2, C104.2, C105.2, C107.2, C108.2, R104.1, R106.1, R108.1, U100.1 (GND), U101.2 (GND), U102.2 (V-); also elsewhere on the board
unnamed: R101.1, R102.2
VBUS: C100.1, L100.1; also elsewhere on the board
VCOM: U102.1, U102.4 (-); also elsewhere on the board

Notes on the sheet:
DCR=0R15
C(in/out)>10uF
V(out)=0.6*(1+100k/22k)=3.327V
I(DC)=500mA
Bias Generator
LP filter: fc=15Hz
100mA max.
f(sw)=1.5MHz
VBUS power comes from USB Type C connector (schematic page 2)
P(R)>1/8W
I(load)=0.25A max
Input Filtering & Analogue and Digital Supplies
[1] Power
WEBENCH Tools

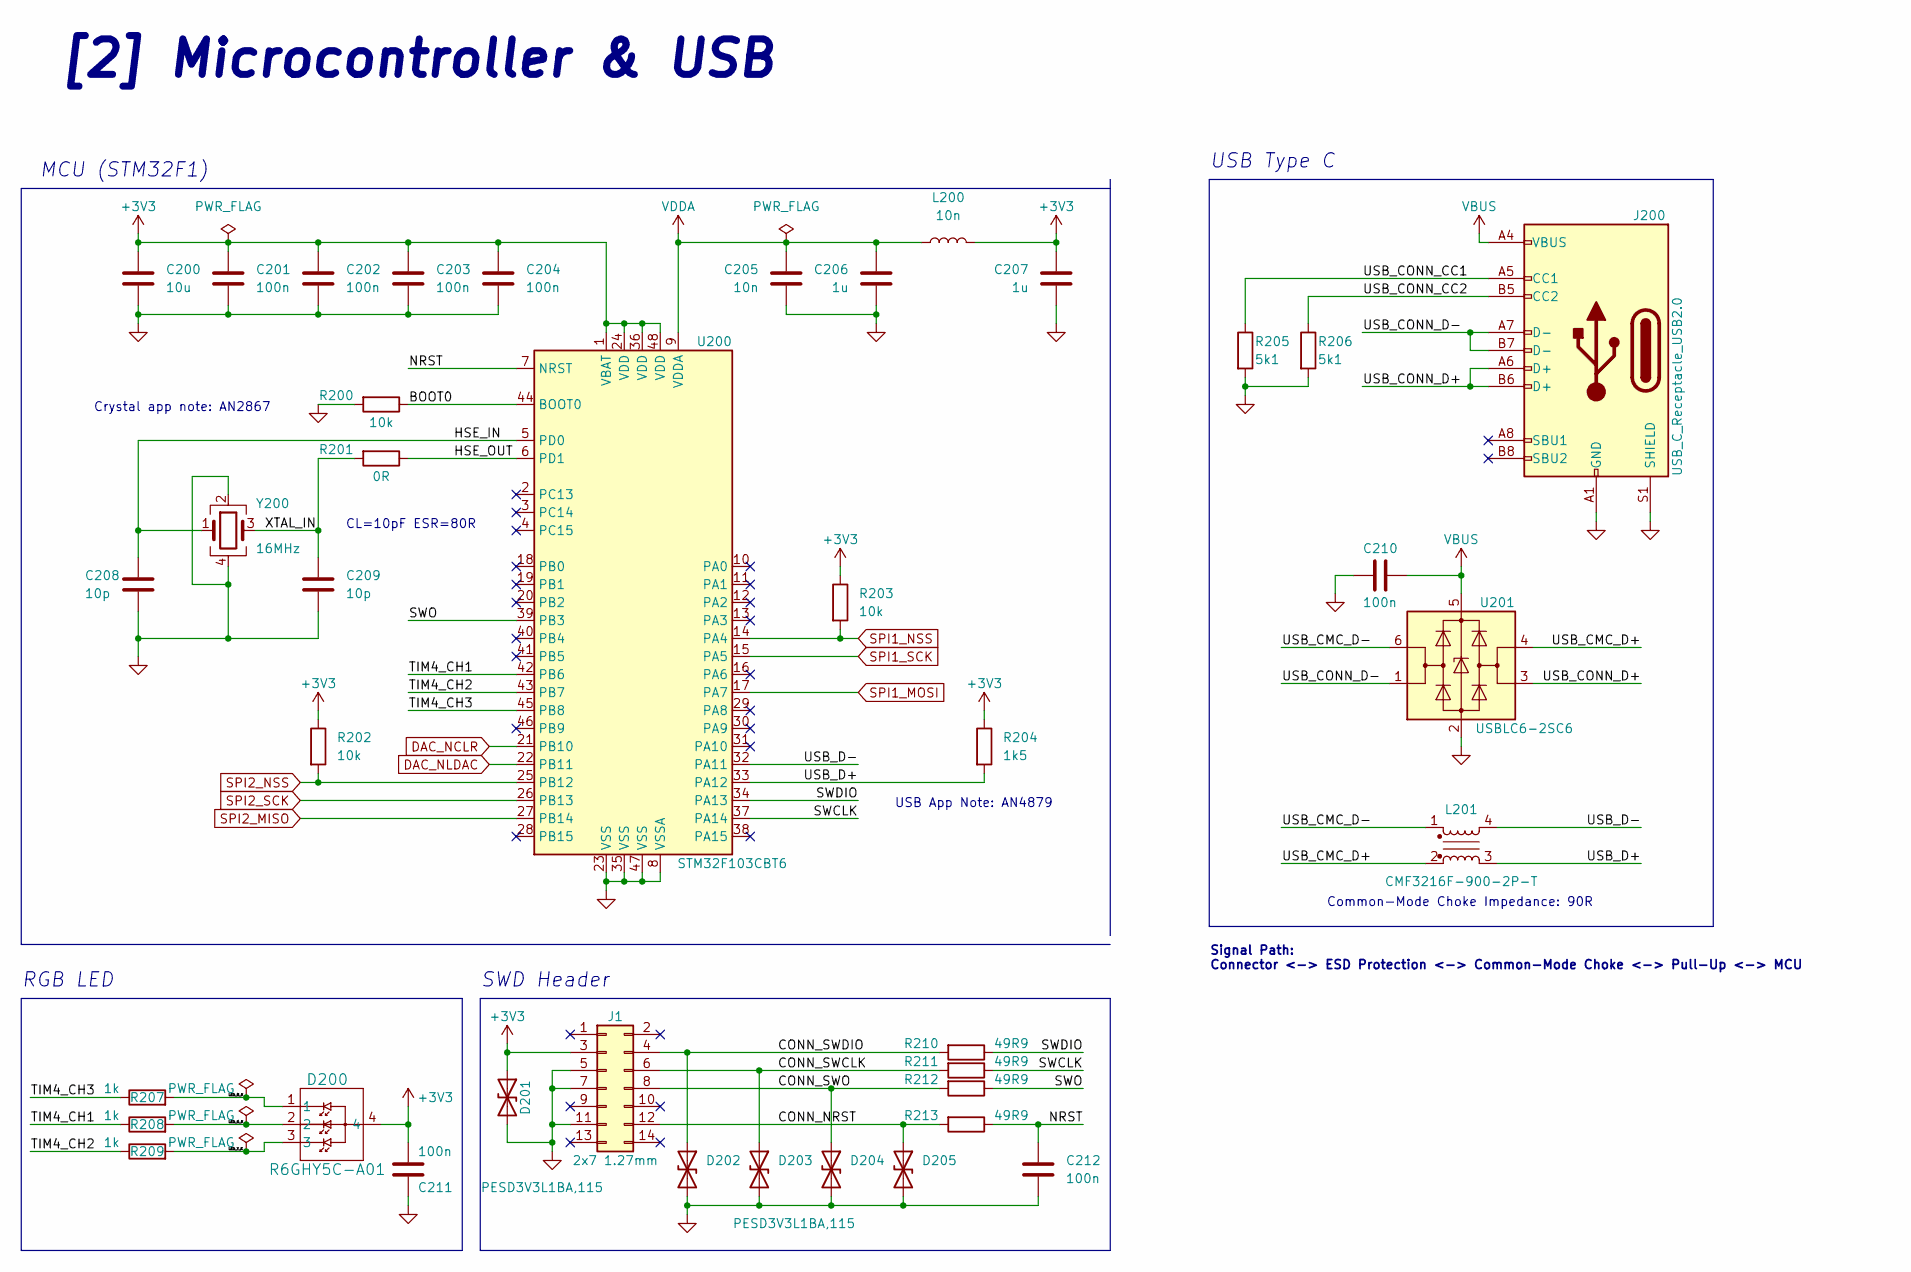
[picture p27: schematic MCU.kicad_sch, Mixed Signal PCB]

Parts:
C200: 10u; C_0603_1608Metric; LCSC C19702
C201, C202, C203, C204, C210, C211, C212: 100n; C_0402_1005Metric; LCSC C1525
C205: 10n; C_0402_1005Metric; LCSC C15195
C206, C207: 1u; C_0603_1608Metric; LCSC C15849
C208, C209: 10p; C_0402_1005Metric; LCSC C32949
D200: R6GHY5C-A01; LCSC C2897364
D201, D202, D203, D204, D205: PESD3V3L1BA,115; D_SOD-323; LCSC C51450
J1: 2x7 1.27mm; 14 Pin IDC 1.27mm; LCSC C2935955
J200: USB_C_Receptacle_USB2.0; TYPE-C-31-M-12; LCSC C165948
L200: 10n; L_0402_1005Metric; LCSC C27147
L201: CMF3216F-900-2P-T; CMC-1206; LCSC C963740
R200, R202, R203: 10k; R_0402_1005Metric; LCSC C25744
R201: 0R; R_0402_1005Metric; LCSC C17168
R204: 1k5; R_0402_1005Metric; LCSC C25867
R205, R206: 5k1; R_0402_1005Metric; LCSC C25905
R207, R208, R209: 1k; R_0402_1005Metric; LCSC C11702
R210, R211, R212, R213: 49R9; R_0402_1005Metric; LCSC C25120
U200: STM32F103CBT6; LQFP-48_7x7mm_P0.5mm; LCSC C8304
U201: USBLC6-2SC6; SOT-23-6; LCSC C7519
Y200: 16MHz; Crystal_SMD_3225-4Pin_3.2x2.5mm; LCSC C13738

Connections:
+3V3: C200.1, C201.1, C202.1, C203.1, C204.1, C207.1, C211.1, D200.4, D201.1 (A1), L200.2, R202.1, R203.1, R204.1, U200.1 (VBAT), U200.24 (VDD), U200.36 (VDD), U200.48 (VDD); also elsewhere on the board
/MCU/BOOT0: R200.1, U200.44 (BOOT0)
/MCU/CONN_NRST: D205.1 (A1), R213.2; also elsewhere on the board
/MCU/CONN_SWCLK: D203.1 (A1), R211.2; also elsewhere on the board
/MCU/CONN_SWDIO: D202.1 (A1), R210.2; also elsewhere on the board
/MCU/CONN_SWO: D204.1 (A1), R212.2; also elsewhere on the board
/MCU/HSE_IN: C208.1, U200.5 (PD0), Y200.1
/MCU/HSE_OUT: R201.1, U200.6 (PD1)
/MCU/LED_G_K: D200.2, R208.2
/MCU/LED_R_K: D200.1, R207.2
/MCU/LED_Y_K: D200.3, R209.2
/MCU/NRST: C212.1, R213.1, U200.7 (NRST)
/MCU/SWCLK: R211.1, U200.37 (PA14)
/MCU/SWDIO: R210.1, U200.34 (PA13)
/MCU/SWO: R212.1, U200.39 (PB3)
/MCU/TIM4_CH1: R208.1, U200.42 (PB6)
/MCU/TIM4_CH2: R209.1, U200.43 (PB7)
/MCU/TIM4_CH3: R207.1, U200.45 (PB8)
/MCU/USB_CMC_D+: L201.2, U201.4 (I/O2)
/MCU/USB_CMC_D-: L201.1, U201.6 (I/O1)
/MCU/USB_CONN_CC1: J200.A5 (CC1), R205.1
/MCU/USB_CONN_CC2: J200.B5 (CC2), R206.1
/MCU/USB_CONN_D+: J200.A6 (D+), J200.B6 (D+), U201.3 (I/O2)
/MCU/USB_CONN_D-: J200.A7 (D-), J200.B7 (D-), U201.1 (I/O1)
/MCU/USB_D+: L201.3, R204.2, U200.33 (PA12)
/MCU/USB_D-: L201.4, U200.32 (PA11)
/MCU/XTAL_IN: C209.1, R201.2, Y200.3
DAC_NCLR: U200.21 (PB10); also elsewhere on the board
DAC_NLDAC: U200.22 (PB11); also elsewhere on the board
GND: C200.2, C201.2, C202.2, C203.2, C204.2, C205.2, C206.2, C207.2, C208.2, C209.2, C210.2, C211.2, C212.2, D201.2 (A2), D202.2 (A2), D203.2 (A2), D204.2 (A2), D205.2 (A2), J200.A1 (GND), J200.A12 (GND), J200.B1 (GND), J200.B12 (GND), J200.S1 (SHIELD), R200.2, R205.2, R206.2, U200.8 (VSSA), U200.23 (VSS), U200.35 (VSS), U200.47 (VSS), U201.2 (GND), Y200.2, Y200.4; also elsewhere on the board
SPI1_MOSI: U200.17 (PA7); also elsewhere on the board
SPI1_NSS: R203.2, U200.14 (PA4); also elsewhere on the board
SPI1_SCK: U200.15 (PA5); also elsewhere on the board
SPI2_MISO: U200.27 (PB14); also elsewhere on the board
SPI2_NSS: R202.2, U200.25 (PB12); also elsewhere on the board
SPI2_SCK: U200.26 (PB13); also elsewhere on the board
VBUS: C210.1, J200.A4 (VBUS), J200.A9 (VBUS), J200.B4 (VBUS), J200.B9 (VBUS), U201.5 (VBUS); also elsewhere on the board
VDDA: C205.1, C206.1, L200.1, U200.9 (VDDA)

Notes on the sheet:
Signal Path: Connector <-> ESD Protection <-> Common-Mode Choke <-> Pull-Up <-> MCU
RGB LED
Crystal app note: AN2867
SWD Header
USB App Note: AN4879
Common-Mode Choke Impedance: 90R
[2] Microcontroller & USB
CL=10pF ESR=80R
MCU (STM32F1)
USB Type C

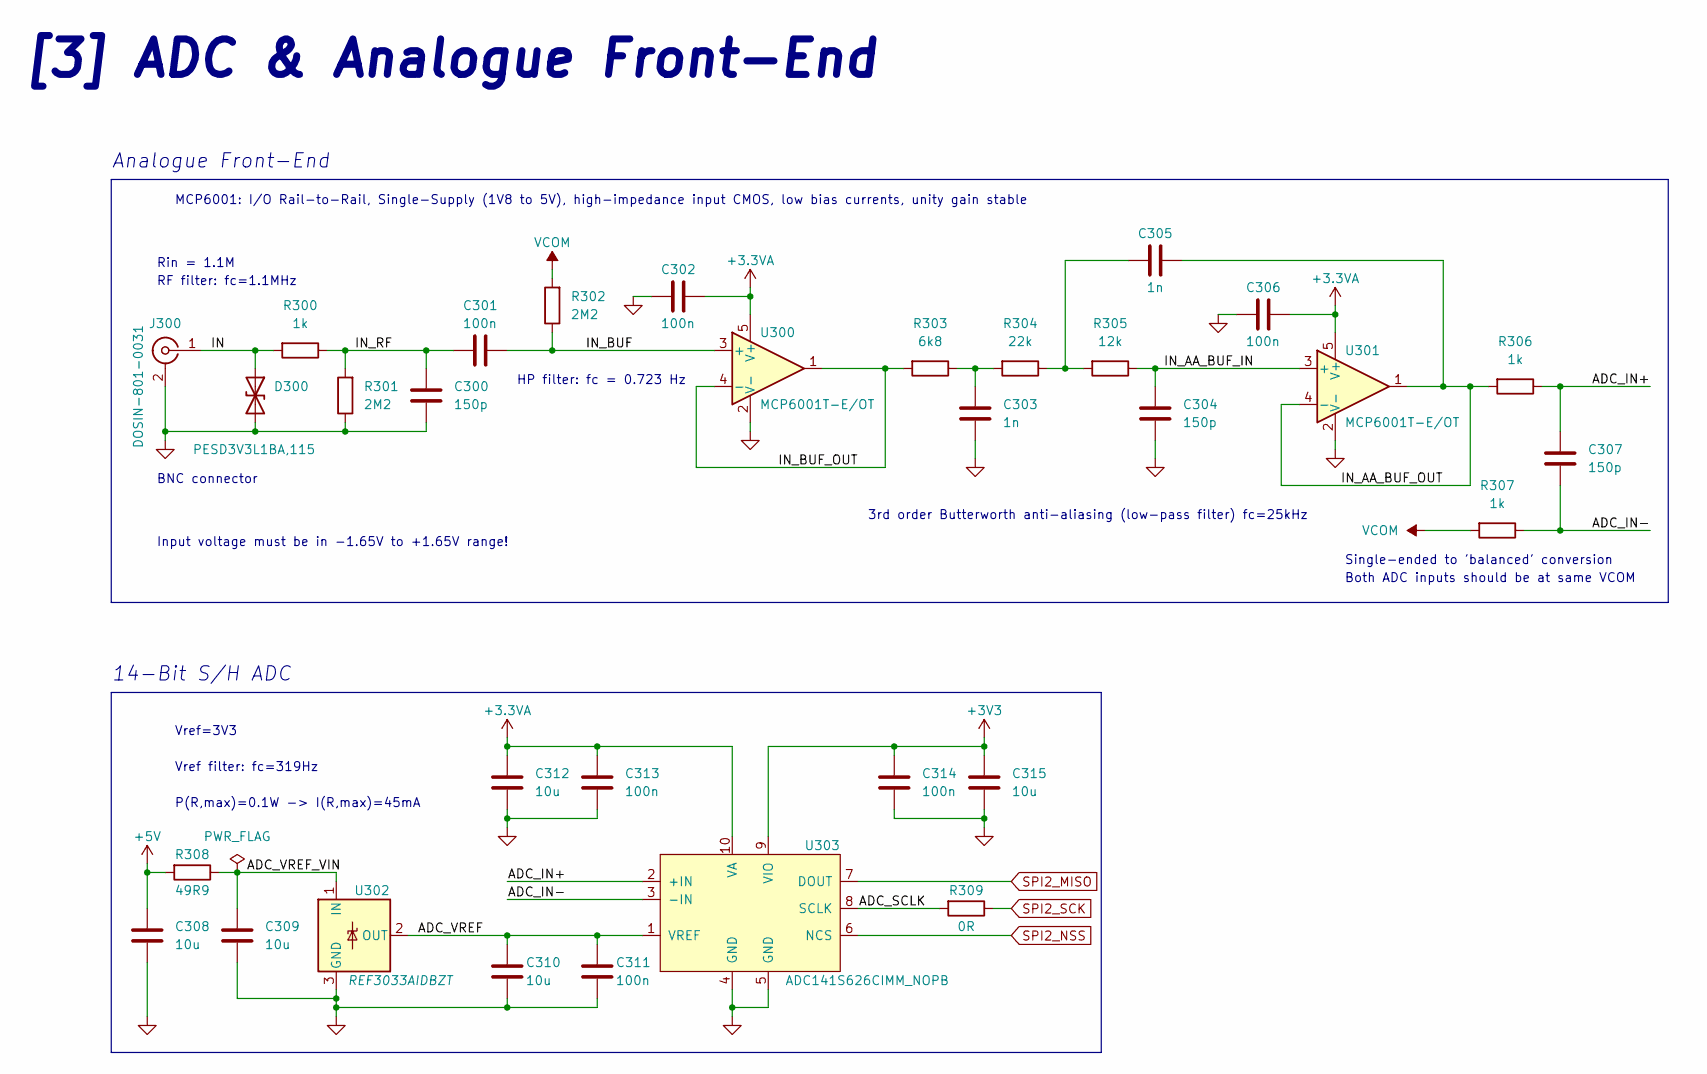
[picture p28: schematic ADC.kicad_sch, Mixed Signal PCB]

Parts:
C300, C304, C307: 150p; C_0402_1005Metric; LCSC C106998
C301, C302, C306, C311, C313, C314: 100n; C_0402_1005Metric; LCSC C1525
C303, C305: 1n; C_0402_1005Metric; LCSC C1523
C308, C309, C310, C312, C315: 10u; C_0603_1608Metric; LCSC C19702
D300: PESD3V3L1BA,115; D_SOD-323; LCSC C51450
J300: DOSIN-801-0031; AMPHENOL-BNC-031-5640-1010; LCSC C521205
R300, R306, R307: 1k; R_0402_1005Metric; LCSC C11702
R301, R302: 2M2; R_0402_1005Metric; LCSC C274901
R303: 6k8; R_0402_1005Metric; LCSC C25917
R304: 22k; R_0402_1005Metric; LCSC C25768
R305: 12k; R_0402_1005Metric; LCSC C25752
R308: 49R9; R_0402_1005Metric; LCSC C25120
R309: 0R; R_0402_1005Metric; LCSC C17168
U300, U301: MCP6001T-E/OT; SOT-23-5; LCSC C29429
U302: REF3033AIDBZT; SOT-23; LCSC C2872391
U303: ADC141S626CIMM_NOPB; VSSOP-10; LCSC C206494

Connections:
+3.3VA: C302.1, C306.1, C312.1, C313.1, U300.5 (V+), U301.5 (V+), U303.10 (VA); also elsewhere on the board
+3V3: C314.1, C315.1, U303.9 (VIO); also elsewhere on the board
+5V: C308.1, R308.2; also elsewhere on the board
/ADC/ADC_IN+: C307.1, R306.1, U303.2 (+IN)
/ADC/ADC_IN-: C307.2, R307.1, U303.3 (-IN)
/ADC/ADC_SCLK: R309.2, U303.8 (SCLK)
/ADC/ADC_VREF: C310.1, C311.1, U302.2 (OUT), U303.1 (VREF)
/ADC/ADC_VREF_VIN: C309.1, R308.1, U302.1 (IN)
/ADC/IN: D300.1 (A1), J300.1 (In), R300.2
/ADC/IN_AA_BUF_IN: C304.1, R305.1, U301.3 (+)
/ADC/IN_AA_BUF_OUT: C305.2, R306.2, U301.1, U301.4 (-)
/ADC/IN_BUF: C301.1, R302.1, U300.3 (+)
/ADC/IN_BUF_OUT: R303.2, U300.1, U300.4 (-)
/ADC/IN_RF: C300.1, C301.2, R300.1, R301.2
GND: C300.2, C302.2, C303.2, C304.2, C306.2, C308.2, C309.2, C310.2, C311.2, C312.2, C313.2, C314.2, C315.2, D300.2 (A2), J300.2 (Ext), R301.1, U300.2 (V-), U301.2 (V-), U302.3 (GND), U303.4 (GND), U303.5 (GND); also elsewhere on the board
unnamed: C303.1, R303.1, R304.2
unnamed: C305.1, R304.1, R305.2
SPI2_MISO: U303.7 (DOUT); also elsewhere on the board
SPI2_NSS: U303.6 (NCS); also elsewhere on the board
SPI2_SCK: R309.1; also elsewhere on the board
VCOM: R302.2, R307.2; also elsewhere on the board

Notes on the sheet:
HP filter: fc = 0.723 Hz
Both ADC inputs should be at same VCOM
BNC connector
Rin = 1.1M
14-Bit S/H ADC
Vref filter: fc=319Hz
Input voltage must be in -1.65V to +1.65V range!
Analogue Front-End
Single-ended to 'balanced' conversion
RF filter: fc=1.1MHz
3rd order Butterworth anti-aliasing (low-pass filter) fc=25kHz
MCP6001: I/O Rail-to-Rail, Single-Supply (1V8 to 5V), high-impedance input CMOS, low bias currents, unity gain stable
P(R,max)=0.1W -> I(R,max)=45mA
Vref=3V3
[3] ADC & Analogue Front-End

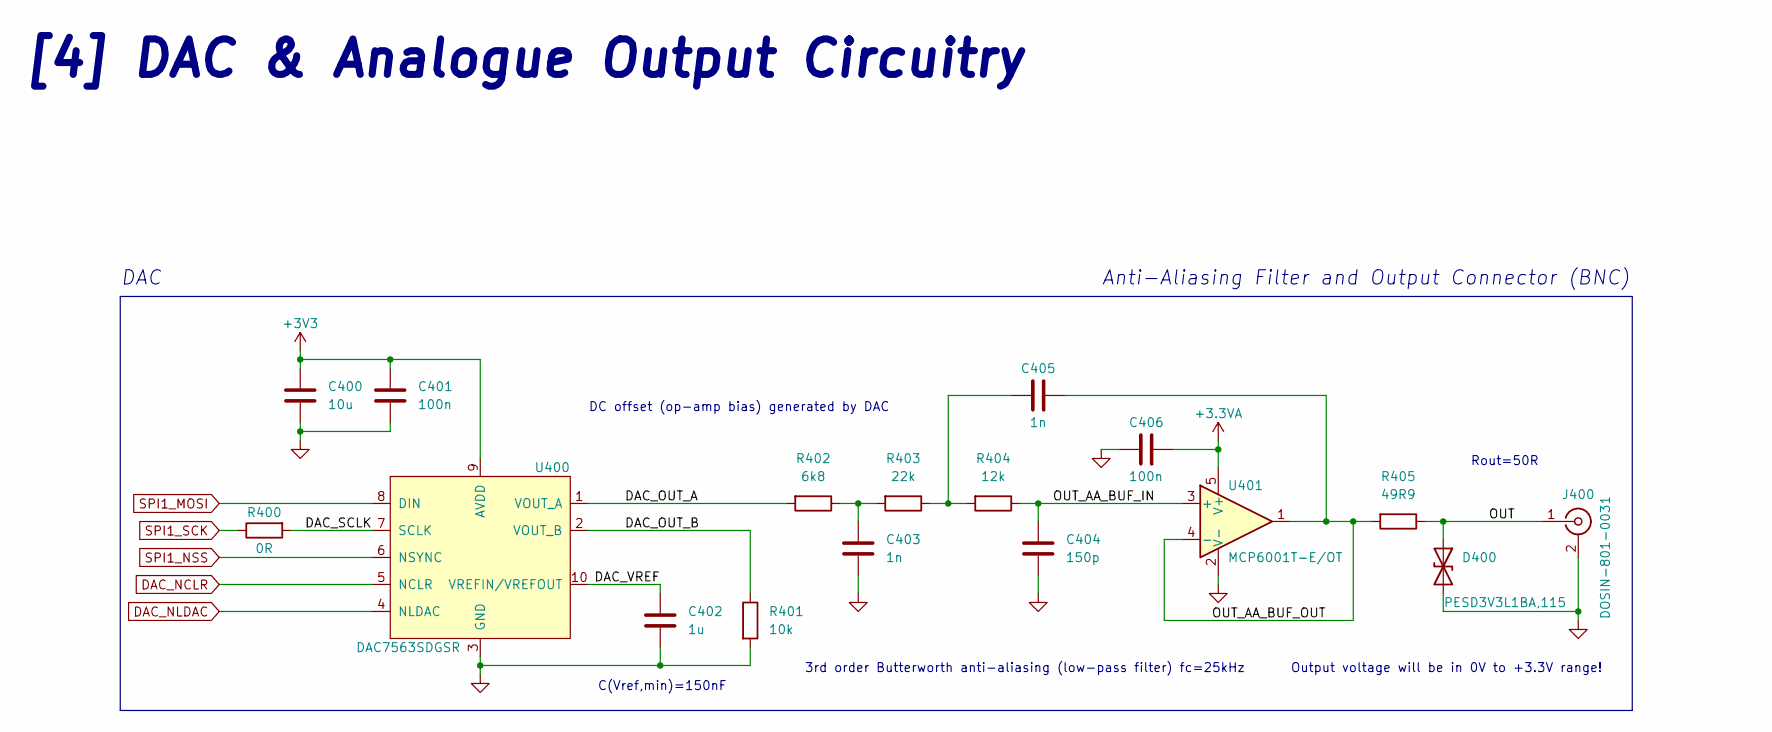
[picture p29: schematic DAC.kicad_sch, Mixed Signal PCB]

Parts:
C400: 10u; C_0603_1608Metric; LCSC C19702
C401, C406: 100n; C_0402_1005Metric; LCSC C1525
C402: 1u; C_0603_1608Metric; LCSC C15849
C403, C405: 1n; C_0402_1005Metric; LCSC C1523
C404: 150p; C_0402_1005Metric; LCSC C106998
D400: PESD3V3L1BA,115; D_SOD-323; LCSC C51450
J400: DOSIN-801-0031; AMPHENOL-BNC-031-5640-1010; LCSC C521205
R400: 0R; R_0402_1005Metric; LCSC C17168
R401: 10k; R_0402_1005Metric; LCSC C25744
R402: 6k8; R_0402_1005Metric; LCSC C25917
R403: 22k; R_0402_1005Metric; LCSC C25768
R404: 12k; R_0402_1005Metric; LCSC C25752
R405: 49R9; R_0402_1005Metric; LCSC C25120
U400: DAC7563SDGSR; VSSOP-10; LCSC C601656
U401: MCP6001T-E/OT; SOT-23-5; LCSC C29429

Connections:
+3.3VA: C406.1, U401.5 (V+); also elsewhere on the board
+3V3: C400.1, C401.1, U400.9 (AVDD); also elsewhere on the board
/DAC/DAC_OUT_A: R402.2, U400.1 (VOUT_A)
/DAC/DAC_OUT_B: R401.1, U400.2 (VOUT_B)
/DAC/DAC_SCLK: R400.2, U400.7 (SCLK)
/DAC/DAC_VREF: C402.1, U400.10 (VREFIN/VREFOUT)
/DAC/OUT: D400.1 (A1), J400.1 (In), R405.1
/DAC/OUT_AA_BUF_IN: C404.1, R404.1, U401.3 (+)
/DAC/OUT_AA_BUF_OUT: C405.2, R405.2, U401.1, U401.4 (-)
DAC_NCLR: U400.5 (NCLR); also elsewhere on the board
DAC_NLDAC: U400.4 (NLDAC); also elsewhere on the board
GND: C400.2, C401.2, C402.2, C403.2, C404.2, C406.2, D400.2 (A2), J400.2 (Ext), R401.2, U400.3 (GND), U401.2 (V-); also elsewhere on the board
unnamed: C403.1, R402.1, R403.2
unnamed: C405.1, R403.1, R404.2
SPI1_MOSI: U400.8 (DIN); also elsewhere on the board
SPI1_NSS: U400.6 (NSYNC); also elsewhere on the board
SPI1_SCK: R400.1; also elsewhere on the board

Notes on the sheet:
[4] DAC & Analogue Output Circuitry
Anti-Aliasing Filter and Output Connector (BNC)
Rout=50R
Output voltage will be in 0V to +3.3V range!
DAC
C(Vref,min)=150nF
3rd order Butterworth anti-aliasing (low-pass filter) fc=25kHz
DC offset (op-amp bias) generated by DAC

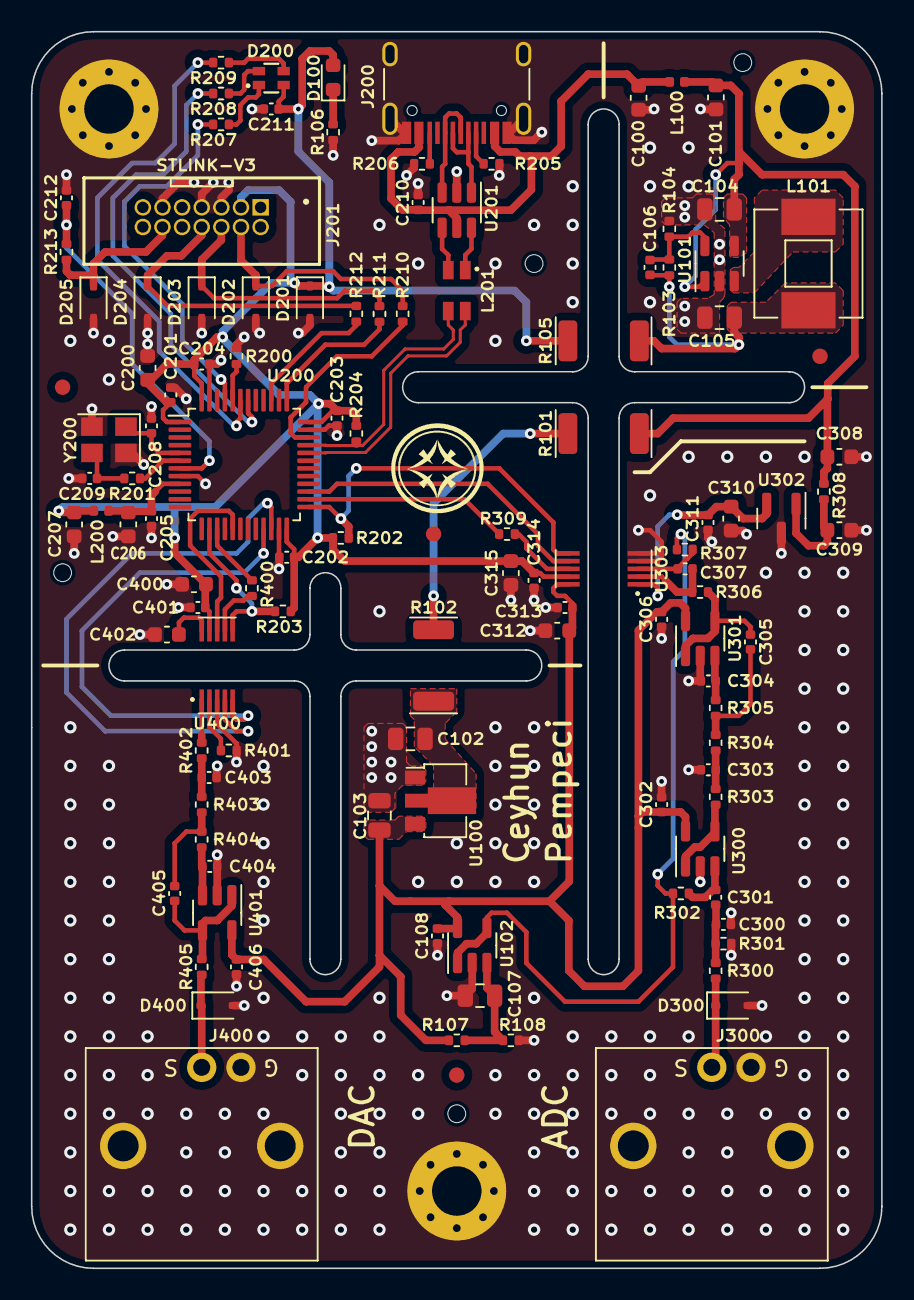
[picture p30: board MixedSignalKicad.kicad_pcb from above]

Board: 2 copper layers, 55.0 x 80.0 mm, 123 parts (0 on the bottom side), 70 nets.

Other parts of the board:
J201: 2x7 1.27mm; 14 Pin IDC 1.27mm

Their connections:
+3V3: J201.3; also elsewhere on the board
/MCU/CONN_NRST: J201.12; also elsewhere on the board
/MCU/CONN_SWCLK: J201.6; also elsewhere on the board
/MCU/CONN_SWDIO: J201.4; also elsewhere on the board
/MCU/CONN_SWO: J201.8; also elsewhere on the board
GND: J201.5, J201.7, J201.11; also elsewhere on the board

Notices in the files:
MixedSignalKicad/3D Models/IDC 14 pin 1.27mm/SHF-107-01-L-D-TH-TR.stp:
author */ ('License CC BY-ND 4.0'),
